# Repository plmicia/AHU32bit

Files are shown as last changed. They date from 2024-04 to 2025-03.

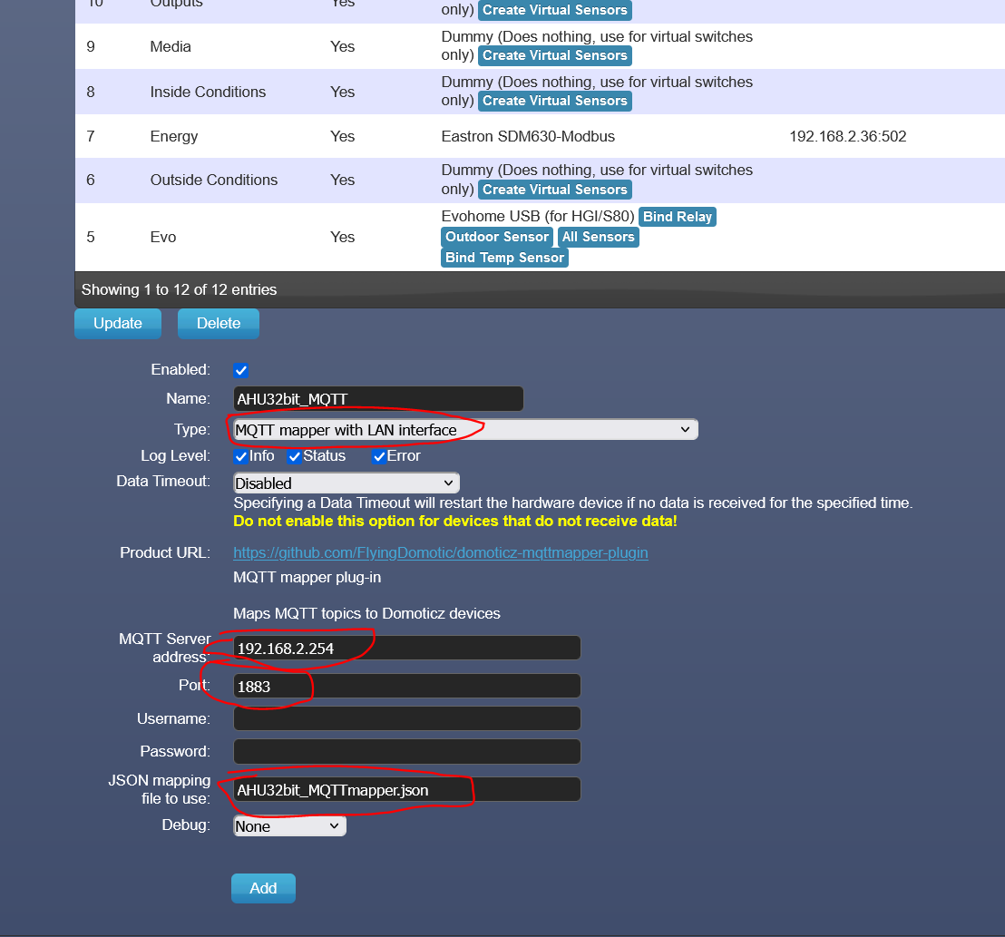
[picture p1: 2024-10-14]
Firmware v3.0.6beta/MQTT Domoticz/konfiguracja Domoticz - devices.PNG

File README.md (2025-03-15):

# AHU32bit 

Heat Pump Controller

Jak połączyć AHU do sieci lokalnej?
https://youtu.be/T4DrFWYFrpU?si=GrnXhtAI3-qEB1rJ

Jak zaktualizować firmware?
https://youtu.be/g_uAfUcfIxk?si=aBbPRCSxZJbn4i6s

**v1.0.0:**
 
Wersja wyjściowa

**v1.1.1:**

Dodanie menu "Wyświetlacz LCD" w którym można:
- ustawić wartość podświetlenia
- ustawić wygaszenie podświetlenia po czasie
- ustawić wartość podświetlenia po wygaszeniu
- zał./wył. wyświetlanie częstotliwości pracy sprężarki na ekranie głównym
  
Dodanie możliwości zablokowania klawiatury poprzez przytrzymanie (~1s) dwóch środkowych przycisków.

Dodanie dłuższego (~1s) przytrzymania przycisku ON/OFF (ochrona przed przypadkowym naciśnięciem).

Możliwość kalibracji czułości przycisków z poziomu konsoli AHU32bit.

Poprawka drobnych błędów:
- likwidacja, występującego czasami, stałego pisku przy wyłączaniu alarmu
- zapis wartości nastawionej temperatury do pamięci przy zaniku zasilania

**v1.1.2:**

- poprawka błędów

**v1.2.3:**

Dodanie menu "Pompa obiegowa" w którym można:
- Ustawić postcyrkulację (opóźnienie wyłączenia pompy obiegowej)
- Wysterować stałą mocą pompę wyposażoną w wejście PWM
- Ustawić parametry wyjścia PWM (częstotliwość PWM)
W menu "Defrost" dodano możliwość ograniczenia czasu wymuszonego defrstu oraz dodano opóźnienie wyłączenia przekaźnika sygnalizującego defrost.

W menu "Zabezpieczenia" można wybrać, kiedy zabezpieczenie od przepływu ma być aktywne: "Zawsze", "Tylko gdy defrost" lub "Nigdy".

Dodano menu "Olejowanie" w którym można ustawić interwał olejowania, częstotliwośc (moc) sprężarki w czasie olejowania oraz czas trwania olejowania. Moża też wymusić olejowanie w celach diagnostycznych.

Dodano menu "Odzysk czynnika".

Poprawiono babole:
- wysterowanie przekaźnika pompy obiegowej
- zapisywanie do pamięci energii pobranej

**v1.3.4:**
- wprowadzono możliwość załącznia CO w zależności od t. zew. (w menu "Ustawienia CO")
- wprowadzono możliwość załączenia pompy obiegowej na zawsze, gdy sterownik jest załączony (w menu "Pompa obiegowa")
- poprawiono identyfikację agregatu 7kW 
- poprawiono wyświetlanie wartości EEV-A i EEV-B dla 7kW
- wprowadzono redukcję obrotów wentylatora przy wyższych temperaturach zewnętrznych dla agregatu 7kW

Poprawka błędów:
- ograniczono zakres nastaw maks. częstotliwość "łagodnego defrostu" od 56Hz do 85Hz
- sporadycznie występujące samoczynne, chwilowe startowanie agregatu, gdy T_cond > 20*C (dot. nowszych jednostek Gree i C&H >2022)
- wyeliminowanie problemów z wyłączaniem agregatu przed osiągnięciem temp zadanej (dot. nowszych jednostek Gree i C&H >2022)
- wyeliminowanie błędu uniemożliwiającego wymuszenie defrostu, gdy T_cond < (T_zew - 6)
- wyeliminowanie błędu uniemożliwiającego fabryczne wywołanie defrostu

**v2.0.0:**
- dodano nagłówki, ułatwiające poruszanie się po menu
- zmiana kroku nieczułości regulatorów CO i CWU z 0.5C na 0.1C
- uruchomiono funkcję ciepłomierza (konieczny czujnik przepływu!)
- rozdzielenie liczników energii: osobno dla CO i osobno dla CWU
- uruchomiono liczniki COP (konieczny czujnik przepływu i licznik energii!)
- dodano możliwość sterowania pompy obiegowej PWM w trybie stałej delty (menu: "Pompa obiegowa" -> "Tryb pracy PWM" -> "Stała delta")
- dodano stronę parametrów "Pompa obiegowa", gdzie można podejrzeć aktualny stan załączenia pompy obiegowej, wartości PWM i deltę.
- dodano możliwość wywołania olejowania co 3h
- zmieniono krok zadawania stałej mocy pracy pompy obiegowej PWM (było co 10%, jest co 1%)
- poprawiono działania klawiszy + i -, dodając funkcję przytrzymania z autoinkrementacją. Po naszemu: przytrzymać dłużej przycisk, aby wartość sama się zwiększała lub zmniejszała
- dodano menu "Liczniki", w którym można wyzerować wartość licznika energii, ilość defrostów, czas pracy sprężarki i ilość załączeń
- wprowadzono dynamic clamping we wszystkich regulatorach PI (znacznie poprawia dynamikę sterowania)

Poprawka błędów:
- wyeliminowanie błędu załączenia CWU wraz z blokadą załączenia CO od T_zew + dodanie ikonki sygnalizującej wyłączenia od temperatury zewnętrznej.
- próba wyeliminowania błędu uniemożliwiającego wymuszenie defrostu (dot. nowszych jednostek Gree i C&H >2022)

Uwaga!!! Aby liczniki energii działały prawidłowo, od teraz po każdej aktualizacji trzeba w pełni zrestartować system (zdjąć zasilanie z płytki bazowej na min. 20 sek.)

**v2.0.1:**

Poprawka błędów:
- aktywacja regulatora CWU

**v2.0.2:**

Poprawka błędów:
- Zapis wartości liczników do pamięci, zaraz po wyzerowaniu w menu. Poprzenio, po zrestowaniu sterownika wartości wracały do wartości sprzed zerowania.
 
**v3.0.5:**
Video poradnik do aktualizacji: https://youtube.com/playlist?list=PL7Yoy5k4_2IOb-d7yyhNmrepyGyvrlC-8&si=gwIATBIfl5vukARS

Płytka wyświetlacza LCD:
- W menu "Ustawienia CO" dodano funkcję "Mniejsze taktowanie". Poprawia ona fabryczną procedurę zadawania częstotliwości sprężarki. Taktowanie jest jeszcze mniejsze, kosztem delikatnego przeregulowania w stanach dynamicznych. Załączenie funkcji pomaga wyeliminować wyłączenia sprężarki przy przełączaniu z CWU na CO oraz po "olejowaniu".
- Wprowadzono funkcję wyłączenia pompy obiegowej, gdy sterownik jest wyłączony od temperatury zewnętrznej (gdy ikonka "słoneczka" na ekranie głównym jest aktywna). Poprawnie ustawiona funkcja pozwala na poprawę COP całego układu, szczególnie w okresach przejściowych. 
- W menu "Liczniki" dodano możliwość wyboru pracy ciepłomierza: "Zawsze" lub "Gdy praca sprężarki". 
- "Moc oddana" o wartości z zakresu od -100W do 100W jest wyświetlana jako "0W" (zero watt) i nie jest wykorzystywana do liczenia energii oddanej. 
- Uporządkowano menu "Defrost". 
- Proszę nie korzystać! TESTY: Dodano funkcję "Indywidualny defrost", gdzie można ustawić: interwał defrostów, zwłokę defrostu po osiągnięciu progu, próg rozpoczęcia defrostu, maksymalny czas defrostu, próg zakończenia defrostu. Funkcja ogranicza lub eliminuje całkowicie występowanie tzw. suchych lub technicznych defrostów. 
- Dodano możliwość wprowadzenia offsetow w czujnikach temperatury w menu "Ust. czujników".
- Dodano identyfikację jednostki GWH09 (3,5kW).
- Wersję oprogramowania można sprawdzić w menu "Inne".
- Tymczasowo wyłączona zostaje funkcja "łagodny defrost". Funkcja wymaga poprawek.
  
Poprawki błędów:
- Strona "Energia": Gdy brak licznika energii pobranej w systemie, to "Moc pobrana" wyświetlana jest jako "0W", a nie "/W".
- Poprawiono błąd, uniemożliwiający start jednostki gdy temperatura parownika (T_cond)<(-9*C).
- Poprawiono drobne błędy w poruszaniu się po menu.

Konsola:
- Dodano obsługę MQTT
- UWAGA! Wyłączono obsługę Telnet.
- Dodano aplikację webową (AHU32bit Console) umożliwiającą podgląd parametrów online oraz podstawowe sterowanie w sieci lokalnej.
- Wprowadzono możliwość ustawienia stałego IP. 

Znane niedociągnięcia w konsoli:
- jeśli AHU nie połączy się z routerem w ciągu około 1 min, np. po utracie zasilania w domu, to konieczne będzie kliknięcie przycisku "zresetuj komunikację" w konsoli

Po aktualizacji należy zresetować system (płytkę LCD i płytkę bazową).

MQTT dla Home Assistant wspaniale opisał @Łukasz Wojtas.

**v3.0.6:**

Płytka wyświetlacza LCD:
- Poprawione wyświetlanie "PWM in" w konsoli i MQTT. Poprzednio wartość była odświeżana tylko gdy na LCD była wyświetlona strona "Pompa obiegowa". 
- Poprawiono zapisywanie wartości parametru "Licz ciepło i moc" z menu "liczniki" do pamięci nieulotnej.
- Wprowadzono możliwość podania wartości przełączenia biegów wentylatora JZ przy pracy CO. Progi dotyczą temperatury parownika i obowiązuje stała histereza 1C.
- Organiczno zakres nastaw czujnika przepływu do 1...1000imp/l
- Do menu "Ustawienia CO" wprowadzono możliwość ustawienie progów zmiany obrotów wentylator jednostki zewnętrznej: "Próg 390/450(490)rpm" oraz "Próg 490/690(790)rpm". Histereza jest stała i wynosi 1C.

Konsola:
- Zmieniono nazwę klienta Mqtt z esp8266client-xxxx na AHU32bit_Client_xxxx
- Poprawiono literówka w słowie "Sprężarka" w zakładce "temperatury".
- Poprawiono wskaźnik temperatury "Falownik" dla jednostki 5kW.
- Wersja konsoli jest wyświetlana w zakładce "Inne"

**v3.0.11:**

UWAGA! Podczas aktualizacji bardzo ważna jest kolejność wgrywania plików!
Video pordanik: https://youtu.be/dtAwadvea6k?si=yNV6m9RhdPWOf3Bx

Płytka wyświetlacza LCD:
- Dodano obsługę GWH12
- Dodano obsługę CH-S24FTXAL-WP
- Dodano zapis parametrów do pamięci przed aktualizacją 
- Zmieniono nazwy temperatur w zakładce 'temperatury' na polskie
- Dodano zabezpieczenie od zamarznięcia parownika. Jeśli różnica temperatury między parownikiem a zewnętrzną przekracza próg z menu ORAZ utrzymuje się przez czas ustawiony w menu, to agregat się wyłączy. Dostępne nastawy w menu "Zabezpieczenia": 
"Min. delta par.-zew.:" oraz "Min. czas błędu par.:"
Alarm sygnalizowany jest na ekranie: Err!(T*)
- Zmieniono dostępne nastawy dla pracy pompy obiegowej: 
"Zawsze gdy ON"
"Gdy praca sprężarki"
"Gdy żądanie CO/CWU"
- Dodano włączenie pompy obiegowej zawsze przy olejowaniu
- Gdy defrost aktywny, to zawór 3D (przekaźnik AUX) zostaje wyłączony. W ten sposób defrost zawsze robiony jest na zład CO.
- Poprawka wysterowania pompy PWM po błędzie zaniku przepływu. 
BYŁO: wartość wynikająca z regulatora delty lub aktualnie ustawiona stała moc.
JEST: 100% mocy
- Zmieniono komendę włączającą najwyższe obroty wentylatora. Lepsza praca przy wyższych mocach i niższych temperaturach.
- Dodano funkcję zapisującą przed aktualizacją aktualne wartości liczników do pamięci.

Konsola:
- W zakładce "Sprężarka" dodano do zegara wyświetlanie częstotliwości zadawanej przez AHU.
- W zakładce "Inne" wyświetlana jest wersja software dla LCD oraz Konsoli.

Po aktualizacji należy zresetować system (płytkę LCD i płytkę bazową).

**v3.1.2:**

Płytka wyświetlacza LCD:
- Uruchomiono funkcję "Indywidualny defrost" w której można indywidualnie sprofilować przegieg defrostu (łagodnie/agresywnie, itp.).

Aby aktywować w pełni "Indywidualny defrost" należy: 
1. Włączyć w menu "Defrost" - > "Indywidualny defrost" -> "Aktywny" na TAK
oraz
2. Włączyć w menu "Defrost" - > "Własny profil" -> "Aktywny" na TAK

Indywidualny defrost jest dwufazowy:
a) faza pierwsza ok. 45Hz, około 3 min,
b) faza II: 65Hz, około 3 min lub szybciej, jeżeli temperatura parownika >20C (lub inna nastawiona).

Dostępne parametry w menu "Indywidualny defrost":
- "Interwał:" czas po którym AHU zacznie sprawdzać temperaturowy próg wyzwolenia defrostu (parametr: "Start defrsotu:"). Wartość domyślna: 90 min. (1,5h).
- "Start defrsotu:" próg temperaturowy wyzwolenia defrostu. Wartość domyślna: -4C. UWAGA! Nie jest to żadna wartość bezwzględna. Jest to różnica temperatur między temperaturą parownika, a temperaturą zewnętrzną!!!
- "Maks. czas defrostu:" czas po którym defrost zostanie ukończony, bez względu na uzyskaną temperaturę parownika. Wartość domyślna: 10 min. Wartość powinna być większa niż suma: 3min + "Faza I (sek.):" + "Faza II (sek.):"
- "Koniec defrostu:" osiągnięcie tej temperatury na parowniku zakończy defrost. Wartość domyślna: 20C
- "Faza I (Hz):" częstotliwość sprężarki podczas fazy I defrostu. Wartość domyślna: 45Hz.
- "Faza I (sek.):" czas trwania fazy I defrostu. Wartość domyślna: 180sek. (3 min)
- "Faza II (Hz):" częstotliwość sprężarki podczas fazy II defrostu. Wartość domyślna: 65Hz.
- "Faza II (sek.):" czas trwania fazy II defrostu. Wartość domyślna: 180sek. (3 min)

Wartości domyślne, są zbliżone do fabrycznych. 

Jeśli defrosty mają być wykonywane częściej, należy zmniejszyć wartość "Interwał" np. z 90 min do 75 min lub zmienić wartość "Start defrostu" (np. zamiast wartości -4C ustawić -3C).
Jeśli defrosty mają być wykonywane rzadziej, należy zwiększyć wartość "Interwał" np. z 90 min do 120 min lub zmienić wartość "Start defrostu" (np. zamiast wartości -4C ustawić -6C).
Jeśli defrost ma przebiegać łagodniej, to należy poeksperymentować z nastawami: "Faza I (Hz):" oraz "Faza II (Hz):". Proszę pamiętać, że zminiejszenie tej wartości może spowodować konieczność wydłużenia defrostu szeczególnie nastawy "Faza II (sek.):" oraz "Maks. czas defrostu:"

Dodatkowo warto zweryfikować nastawy zabezpieczeń w menu "Zabezpieczenia":
- "Minimalna tempeartura rury cieczowej:" próg zadziałania zabezpieczenia od za niskiej temperatury na rurze cieczowej. Wartość należy dobrać do swojej instalacji eksperymentalnie. Wartość domyślna: -5C.
- "Minimalny przepływ:" próg zadziałania zabezpieczenia od za niskiego przepływu. Wartość należy dobrać do swojej instalacji eksperymentalnie. Wartość domyślna: 500l/h.
- "Minimlany czas błędu:" po tym czasie od przekroczenia progu błędu, zostanie zasygnalizowany błąd. Wartość domyślna: 2s. Wartość zalecana: 1-5s.
- "Minimalna delta parownik-zewnętrzna:" próg temperaturowy wyzwolenia zabezpieczenia od zamarznięcia parownika. Wartość domyślna: -10C. UWAGA! Nie jest to żadna wartość bezwzględna. Jest to różnica temperatur między temperaturą parownika, a temperaturą zewnętrzną!!!
- "Minimalny czas błędu parownik-zewnętrzna" po tym czasie od przekroczenia progu błędu "Minimalna delta parownik-zewnętrzna:", zostanie zasygnalizowany błąd. Wartość domyślna: 90 min (1,5h). Wartość zalecana: dłuższa lub równa "Interwał:" w menu "Indywidualny defrost".

Zaleca się ustawić "Postcyrkulację" na minimum 5 min. w menu "Pompa obiegowa".

Defrost indywidualny jest sygnalizowany na ekranie głównym napisem 'CUSTOM' pod ikoną śnieżynką, w momencie jego trwania. 
Odliczany minimalny czas do kolejnego defrostu, widoczny jest w zakładce "Defrost".
Odliczany maksymalny czas do zakończenia trwającego defrostu, widoczny jest w zakładce "Defrost".
Praca sprężarki podczas defrostu indywidualnego rozpoczyna się po około 3 min, od ukazania się ikonki sygnalizującej defrost ("śnieżynka").
Przełączenie na grzania po zakończeniu defrostu trwa około 3 min.

Aby próbnie wywołać defrost indywidualny, należy wybrać "Wymuś indywidualny defrost". Na rozpoczęcie fazy I defrostu trzeba poczekać około 3min.

"Defrost indywidualny" nie powoduje blokowania defrostu fabrycznego. Jeśli agregat uzna, że musi wykonać "suchy" lub "techniczny" defrost to go wykona.

Warunki rozpoczęcia odliczania w dół do "Indywidualnego defrostu": praca sprężarki ORAZ temperatura parownika <0C. Jeśli w czasie odliczania temperatura parownika będzie >=0C, to czas do defrostu zacznie się liczyć do góry (zwiększać się). Może się tak stać np. nad ranem, gdy temperatura zewnętzna urośnie.

Waruknki rozpoczęcia "Indywidualnego defrostu": odliczony  czas (nastawa "Interwał") ORAZ spełniony warunek temperaturowy (nastawa "Start defrostu").

Warunki zakończenia "Indywidualnego defrostu": osiągnięcie zadanej temperatury na parowniku (nastawa "Koniec defrostu:") LUB minięcie nastawy czasu "Faza I (sek.):" + "Faza II (sek.):" LUB minięcie nastawy czasu "Maks. czas defrostu:".

- Menu "Defrost": usunięto funkcję "Łagodny defrost" w starym wydaniu. Zastąpiono ją nową funkcją "Własny profil".

**v3.1.3:**

Aktualizacja od wersji 1.x.x lub 2.x.x :https://www.youtube.com/watch?v=skZjCgosQtY&list=PL7Yoy5k4_2IOb-d7yyhNmrepyGyvrlC-8&index=1&t=78s
Aktualizacja od wersji: 3.x.x: https://youtu.be/dtAwadvea6k?si=yNV6m9RhdPWOf3Bx

UWAGA! Podczas aktualizacji bardzo ważna jest kolejność wgrywania plików!

Płytka wyświetlacza LCD:
- Zmodyfikowano sposób wyświetlania wartości czasu do kolejengo defrostu w zakładce "Defrost". 
BYŁO: wartość w sekundach
JEST: wartość w formacie HH:MM:SS

- Zmodyfikowano sposób wyświetlania wartości czasu do zakończenia defrostu w zakładce "Defrost". 
BYŁO: wartość w sekundach
JEST: wartość w formacie MM:SS

- Dodano możliwość wyboru sposobu raportowania T gaz do JZ w menu "Ust. czujników"->"Pomiar T gaz"->"Sposób pomiaru":
  
a) "Tylko T gaz" - AHU raportuje do JZ T gaz jako rzeczywistą pomierzoną wartość, bezpośrednio z czujnika

b) "Średnia T gaz i T ciecz" - AHU raportuje do JZ i wyświetla T gaz, jako średnią ważoną pomiaru T gaz oraz T ciecz. Wagi również można ustawić w menu 

- Odliczanie do kolejnego defrostu:
BYŁO: resetowanie po wystąpieniu błędu (odliczanie od początku)
JEST: pozostaje poprzednia wartość

- Wzmocniono filtrowanie progów błędu od za niskiej temperatury, przepływu i delty zew.-parownik.

Konsola:

- poprawiono layout zakładki "Inne" na urządzeniach mobilnych (wyświetlanie kafelka z wersją oprogramowania)
- zmieniono zakres wskaźników dla temperatur ujemnych, BYŁO: 0C - 100C, JEST -40C - 100C

**v3.2.6:**

Płytka wyświetlacza LCD:

- Zwiększono czytelność wprowadzania nastaw zadanej temperatury po naciśnięciu klawiszy plus i minus (wyświetlanie dodatkowego okna pop-up).
- Zamieniono przycisk "minus" z "plus" i vice versa, aby był spójny z układem przycisków w konsoli. 
- Zamieniono przycisk "up" z "down" i vice versa.
- Zmieniono miejsce wyświetlania częstotliwości, tak aby była widoczna podczas przeglądania zakładek oraz menu (prawy górny róg). 
- Dodano możliwość wyświetlenia dwóch dodatkowych parametrów na ekranie głównym. Wyboru parametrów w można dokonać w menu "Wyświetlacz LCD" ->"Pokaż na stronie głównej [pole I]" oraz "Pokaż na stronie głównej [pole II]". 
- Poprawiono raportowanie "PWM out" podczas trwania defrostu, itp.
- Poprawiono raportowanie częstotliwości zadanej podczas trwania defrostu oraz olejowania.
- Dodano wyświetlanie przepływu w zakładce "Pompa obiegowa".
- W menu "Inne" można włączyć/wyłączyć "Dźwięk alarmów" (pikanie).
- Wydłużono czas stanu "Aktualnie pod indywidualnym defrostem" o 3 min od momentu wyłączenia sprężarki.
- Dodano możliwość ustawienia obrotów wentylatora JZ podczas olejowania (w mneu "Olejowanie")
- Dodano możliwość ustawienia progu załączenia maksymalnej (810rpm) wartości obrotów wentylatora JZ (w menu "Ustawienia CO"->"Wentylator JZ")
- Korekta wyświetlanych wartość w zakładce "Energia", szczególnie po wyzerowaniu liczników.

Konsola:

- Gdy "Indywidualny defrost" włączony, dodano kafelek odliczający czasy do kolejnego defrostu i do zakończenia defrostu.
- Poprawiono wyświetlanie flagi "Aktualnie pod defrostem" podczas trwania defrostu indywidualnego.
- Poprawiono wysyłanie do konsoli i MQTT flagi "Aktualnie pod indywidualnym defrostem".
- Dodano wyświetlanie drugiej temperatury parownika (przydatne przy diagnostyce gazowej).
- Dodano do protokołu MQTT wysyłanie wersji firmware LCD.

**v3.2.8:**

Płytka wyświetlacza LCD:

- W menu "Defrost"->"Fabryczne defrosty" dodano możliwość pomijania fabrycznych defrostów (w tym suchych/technicznych).

Możliwe nastawy:

"Wykonuj" - nastawa standardowa. Gdy agregt zadecyduje o defroście (nawet suchym/technicznym) to AHU nie zablokuje jego wykonania.

"Pomijaj" - gdy AHU otrzyma z agregartu sygnał o rozpoczęciu fabrycznego defrostu, to wyłącza agregat i załącza grzanie ponownie. 

UWAGA! Efekt uboczny: przerwa ok. 3 min w pracy agregartu! 
Nastawa "Pomijaj", będzie aktywna tylko gdy "Indywidialny defrost" ustawiony na "TAK" ORAZ "Własny profil" ustawiony na "TAK".  

**v4.0.9:**

UWAGA! UWAGA! UWAGA!
Kolejność wgrywania plików inna niż zwykle:
1. AHU32bit_Console_Firmware.bin
2. AHU32bit_LCD_Firmware.bin
3. AHU32bit_Console_FileSystem.bin
   
Wideo poradnik: https://www.youtube.com/watch?v=JyJtdb9cDpk

Płytka wyświetlacza LCD:

- Dodano dwupunktową linearyzację czujnika przepływu YF-B10. Poprawia dokładność liczenia mocy i energii oddanej dla małych przepływów. Szczególnie ważne dla pomp obiegowych PWM!
Funkcję można włączyć w 'Menu'->'Ust. czujników'->'Czujnik przepływu'->'Linearyzacja'->'Dwupunktowa'.
Wartości domyślne obowiązują dla czujnika YF-B10.
Własne wartości można podać w parametrach, gdy parametr "Linearyzacja" jest ustawiony na "Jednopunktowa":
"Przepływ-odczyt min.:" wartość przepływu odczytana przez AHU @ 10% PWM
"Przepływ-znany min.:" wartość przepływu odczytana z fabrycznego ciepłomierza/miernika przepływu @ 10% PWM
"Przepływ-odczyt max.:" wartość przepływu odczytana przez AHU @ 100% PWM
"Przepływ-znany max.:" wartość przepływu odczytana z fabrycznego ciepłomierza/miernika przepływu @ 100% PWM
Po podaniu własnych wartości należy przestawić parametr "Linearyzacja" na "Dwupunktowa"
Wartości PWM dla pompy obiegowej, można zadać w trybie pracy pompy obiegowej "Stała moc" w menu "Pompa obiegowa".
- W menu „Ustawienia CO” dodano funkcję "Łagodny rozruch CO" przybliżającą profil rozruchu do fabrycznego sterowania. Uwaga! Funkcja jest domyślnie AKTYWNA. Dezaktywacji można dokonać w menu.
Aktywność funkcji jest sygnalizowana na wyświetlaczu za pomocą ikonki z napisem "Soft".
- Dodano zakładkę "Alarmy", gdzie można podejrzeć aktualne błędy AHU oraz jednostki zew. Błędy AHU32bit są opisane wraz z podpowiedzią gdzie szukać rozwiązania. Błędy agregatu opisane są zgodnie z fabrycznym opisem z dokumentacji serwisowej (po angielsku, wg. oryginalnej pisowni).
Uwaga! Pojawienie się błędu agregatu (jednostki zewnętrznej) nie powoduje zatrzymania AHU32bit. W przypadku ustania błędu, jednostka zewnętrzna powinna powrócić do pracy.
- Dodano zegar RTC wyświetlany na pasku górnym. Zegar można nastawić w menu "Wyświetlacz LCD"->"Zegar RTC". Zegar można też ukryć zmieniając nastawę parametru "Pokaż zegar na pasku" w tym samym menu. Aby zegar chodził po utracie zasilania, do panelu LCD należy włożyć litową bateryjkę pastylkową 3V typu CR1220. 
- Sygnalizacja trybu "Emulacji jednostki wewnętrznej" ikonką na ekranie głównym "EMU"
- Delikatna zmiana w regulatorze stałej delty pompy obiegowej - poprawa dynamiki. 
- W trybie "Emulacji fabrycznej jednostki wewnętrznej" ignorowane jest "Olejowanie" oraz "Indywidualny defrost". Nastawa "Pomijaj fabryczne defrosty" również jest ignorowana.
- Po załączeniu funkcji odzysku czynnika, pompa obiegowa jest załączana na maks. moc.
- Poprawiono literówki w menu (np. "ź" zamiast "z" w "Dźwięk alarmów", itp.)
- Zmodyfikowano protokół komunikacyjny między LCD a modułem komunikacyjnym ESP

Konsola:

- Dodano możliwość pełnego zdalnego sterowania LCD z poziomu konsoli. Z uwagi na ograniczenia sprzętowe pasma transmisyjnego widok ekranu LCD jest odświeżany około raz na sekundę. Należy mieć na uwadze delikatne opóźnienia przeglądając menu zdalnie. Wskazana cierpliwość przy modyfikowaniu nastaw. Funkcja z założenia do wykorzystania sporadycznego ;-). 
- Zmodyfikowano obszar nastawiania temperatury zadanej. Dodano wskaźnik graficzny aktualnego przesunięcia równoległego gdy krzywa grzewcza/pogodowa jest aktywna oraz wskaźnik graficzny zadanej temperatury gdy krzywa grzewcza/pogodowa nie jest aktywna. 
- Dodano zakładkę "Alarmy", gdzie można podejrzeć aktualne błędy AHU oraz jednostki zew. Błędy AHU32bit są opisane wraz z podpowiedzią gdzie szukać rozwiązania. Błędy agregatu opisane są zgodnie z fabrycznym opisem z dokumentacji serwisowej (po angielsku, wg. oryginalnej pisowni).
- Dodano możliwość załączenia i wyłączenia ahu oraz modyfikacji temperatury zadanej z poziomu MQTT. UWAGA! KAŻDA ZMIANA POWODUJE ZAPIS PARAMETRÓW DO PAMIĘCI NIEULOTNEJ WYŚWIETLACZA LCD! NIE JEST ZALECANA MODYFIKACJA PARAMETRÓW W SPOSÓB CIĄGŁY (NP. REALIZACJA KRZYWEJ POGODOWEJ) Z UWAGI NA OGRANICZONĄ ILOŚĆ CYKLI ZAPISÓW DO PAMIĘCI. 
- Zmodyfikowano protokół komunikacyjny między LCD a modułem komunikacyjnym ESP
- Dodano do transmisji MQTT topic: "AHU32bit/realtime/LCD_firmware", gdzie raportowana jest wersja firmware LCD w postaci stringa X.X.X.
- Zmiana biblioteki MQTT na asynchroniczną.

Poprawki konsoli:
- informacje na temat indywidualnego defrostu w zakładce "defrost" (np. odliczanie czasu, itp.) są ukrywane w trybie "Emulacji jednostki wew."

Uwaga! Z uwagi na zwiększone obciążenie transmisji danych, sporadycznie (szczególnie w czasie zdalnego przeglądania menu LCD) może pojawić się glitch (zakłócenie) w transmisji. Objawia się on w postaci szpilki na wykresach z rejestracji pracy sterownika.

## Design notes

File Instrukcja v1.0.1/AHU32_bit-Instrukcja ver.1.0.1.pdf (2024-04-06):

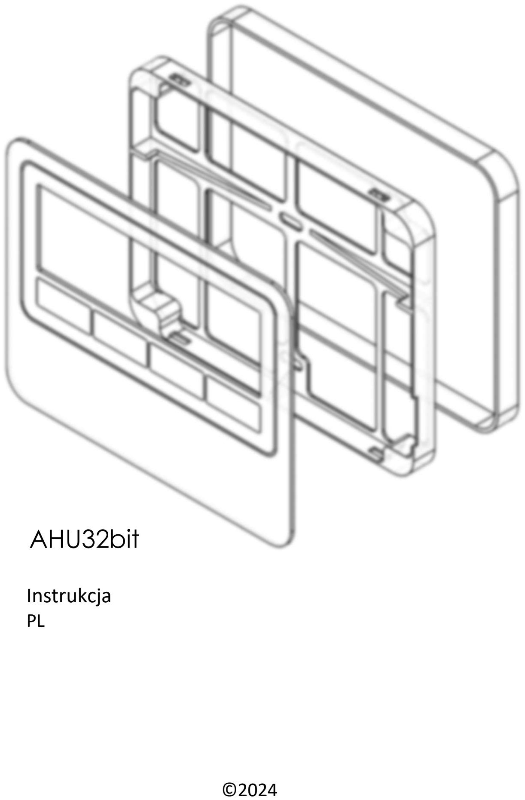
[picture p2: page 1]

©2024

## AHU32bit

### Instrukcja

PL

FabLabPro
ver. 1.0.1.

©2024
v1.0.0.
FabLabPro | 2 / 2 0

## Spis treści:

ver. 1.0.1.

©2024
v1.0.0.
FabLabPro | 3 / 2 0

### 1. Wstęp

Dziękujemy za zakup sterownika AHU32bit. Niniejsza instrukcja pokaże jak zamontować i uruchomić sterownik w poprawny i bezpieczny sposób. Dopełniliśmy wszelkich starań, aby jego instalacja sprawiła wiele przyjemności, a efekt cieszył oko przez długi czas. W razie jakichkolwiek pytań, czy uwag prosimy się zgłaszać pod adres e-mail: ciackamichal@gmail.com. Chcąc być na bieżąco z
aktualizacjami | oraz | wiadomościami | subskrybuj | media
społecznościowe projektu:
| AHU32bit
| AHU32bit
| #AHU32bit
Pompa ciepła - OPEN SOURCE Projekt sterowania i monitoringu w jednym
POMPA CIEPŁA - ࡀ࠿ JAK ZROBIĆ ࡀ࠿ -
| FORUM

### 2. Zawartość zestawu

W jego skład wchodzą:
- Zmontowana płytka drukowana LCD (1 szt.)
- Zmontowana płytka drukowana Bazowa (1 szt.) z wtyczkami
- Kołki montażowe do płytki BAZA (4 szt.)
- Ramka montażowa do płytki LCD (1 szt.) - GRATIS
- Czujniki temperatury typu NTC 10k B3950 (4 szt.)
- Izolacja termokurczliwa z oznaczeniami czujników (8 szt.)
- Kabel 1m typu Ethernet RJ45 (1 szt.)

ver. 1.0.1.

©2024
v1.0.0.
FabLabPro | 4 / 2 0

### 3. Podstawowe cechy

Ważne!
Sterownik jest przeznaczony do wbudowania w istniejący system grzewczy z pompa ciepła. Sterownik nie jest przeznaczony do pracy poza systemem grzewczym!
Sterownik AHU32bit to urządzenie umożliwiające sterownie prestiżowymi agregatami powietrznymi. AHU32bit zastępuje jednostkę wewnętrzną. Podstawowym zadaniem AHU32bit jest stabilizacja temperatury zasilania systemu grzewczego na zadanym poziomie. Możliwy jest wybór temperatury grzania za pomocą wejść bezpotencjałowych, osobno dla CO i CWU.
Uwaga! Do pełnej pracy w trybie CWU niezbędny jest sterownik (termostat) załączający zawór 3D oraz ewentualni dodatkową pompę.
Stabilizacja jest w pełni proporcjonalna i w zakresie modulacji instalacji.
Zadana wartość temperatury może pochodzić z krzywej grzewczej lub mieć stałą wartość.
Właściwości:
- Duży, czytelny wyświetlacz graficzny (4.5”).
- Przyciski dotykowe.
- Tryb Lato/zima.
- Krzywa pogodowa.
- Podgląd wszystkich parametrów dostępnych w systemie:
- Temperatury: zasilania, powrotu, gazu, cieczy, zewnętrznej, parownika, sprężarki, falownika,
- Parametry pracy sprężarki: częstotliwość, moc elektryczna (konsumowana), energia elektryczna (konsumowana), prąd AC, napięcie DC.
- Wysterowanie EEV,

ver. 1.0.1.

©2024
v1.0.0.
FabLabPro | 5 / 2 0
- Obroty wentylatora jednostki zewnętrznej,
- Funkcje statystyczne:
- Ilość załączeń sprężarki,
- Ilość defrostów,
- Łączny czas pracy sprężarki
- Wyjścia przekaźnikowe:
- Sygnalizacja defrostu,
- Alarm,
- Pompa obiegowa,
- AUX (docelowo do sterownia biwalentnego).
- Zabezpieczenia:
- Zaniku przepływu,
- Spadku temperatury,
- Błędu czujnika.
- Sterowanie pogodowe

### 4. Niezbędne narzędzia i materiały do montażu

Zakładamy, że osoba montująca sterownik AHU32bit posiada zaawansowaną wiedzę i umiejętności w zakresie pomp ciepła oraz elektryki. Płytkę bazową sterownika należy zabudować w szczelnej szafie sterowniczej. Płytkę wyświetlacza LCD zamontować na zewnątrz szafy sterowniczej w dostępnym miejscu. Z elementami sterownika należy się obchodzić delikatnie.
Niezbędne narzędzia:
- Mały wkrętak płaski (max. 3mm)
- Przewód do przedłużenia czujników temperatury (doskonale nadaje się skrętka internetowa, ma akurat 4 skręcone pary przewodów). Długość przewodów należy dostosować do własnej instalacji.

ver. 1.0.1.

©2024
v1.0.0.
FabLabPro | 6 / 2 0
- Złączki lub lutownica i cyna do połączenia przewodów z czujnikami

Może się również przydać:

- Wiertarka
- Wiertła
- Praska do zaciskania tulejek na przewodach

### 5. Montaż mechaniczny

Płytkę bazową należy zamontować w szafce sterowniczej tak, aby zapewnić swobodny dostęp do złącz. W przypadku montażu na płycie montażowej, można do tego celu użyć kołków montażowych dostarczonych w zestawie.

UWAGA!!! W sterowniku, podczas pracy występuje napięcie niebezpieczne dla zdrowia i życia człowieka. Montaż oraz podłączenie należy przeprowadzić ze szczególną ostrożnością, przy wyłączonym napięciu!

ver. 1.0.1.

©2024
v1.0.0.

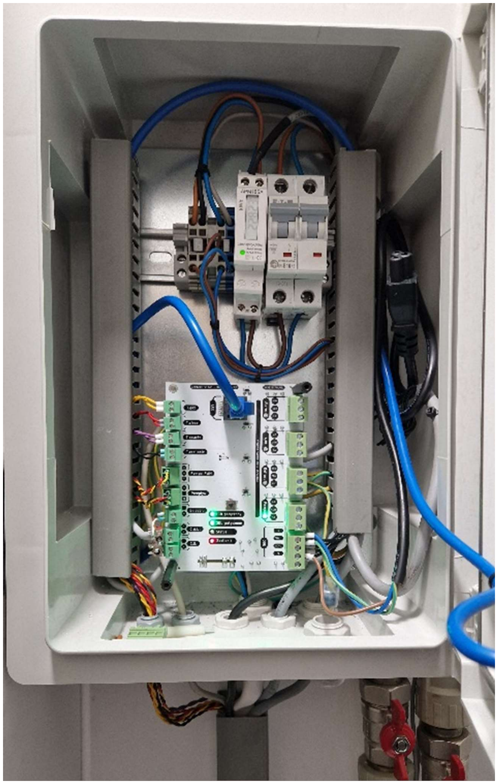
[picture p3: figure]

FabLabPro | 7 / 2 0

Płytkę LCD można zamontować na elewacji za pomocą dostarczonej w zestawie ramki montażowej. Ramka jest też przystosowana do montażu ze standardową puszką instalacyjną 60mm.

ver. 1.0.1.

©2024
v1.0.0.

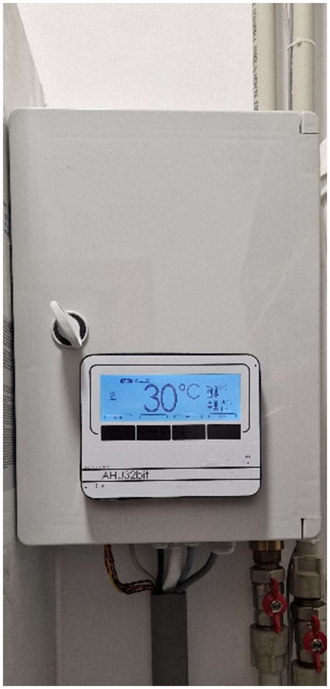
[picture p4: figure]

FabLabPro | 8 / 2 0

Po montażu można zdjąć folie ochronne na ekranie oraz ramce montażowej.

### 6. Podłączenie

### 6.1 Podłączenie sygnału żądania grzania CO i CWU

Aby sterownik rozpoczął pracę konieczne jest podanie sygnału zewnętrznego na bezpotencjałowe wejście żądania grzania CO lub CWU.

W klasycznej aplikacji na wejściu żądania CO należy wykonać zworę, a do wejścia żądania grzania CWU naley podłączyć termostat.

ver. 1.0.1.

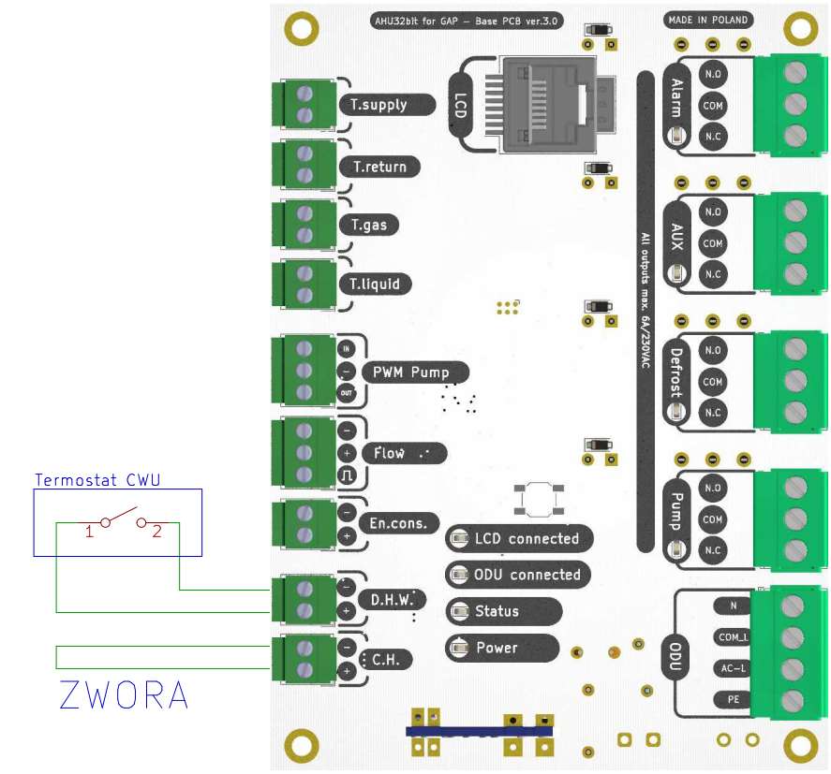
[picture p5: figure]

©2024
v1.0.0.
FabLabPro | 9 / 2 0

Termostat CWU należy podłączyć zgodnie z zaleceniami producenta. Należy pamiętać, że wejście żądania grzania CWU w AHU32bit jest bezpotencjałowe.

Uwaga! Pojawienie się potencjału na wejściu żądania grzania CO oraz CWU uszkodzi sterownik!

### 6.2 Podłączenie zasilania i komunikacji z agregatem

Podłączenie zasilania i komunikacji z agregatem dokonujemy identycznie jak dla fabrycznej jednostki wewnętrznej.

ver. 1.0.1.

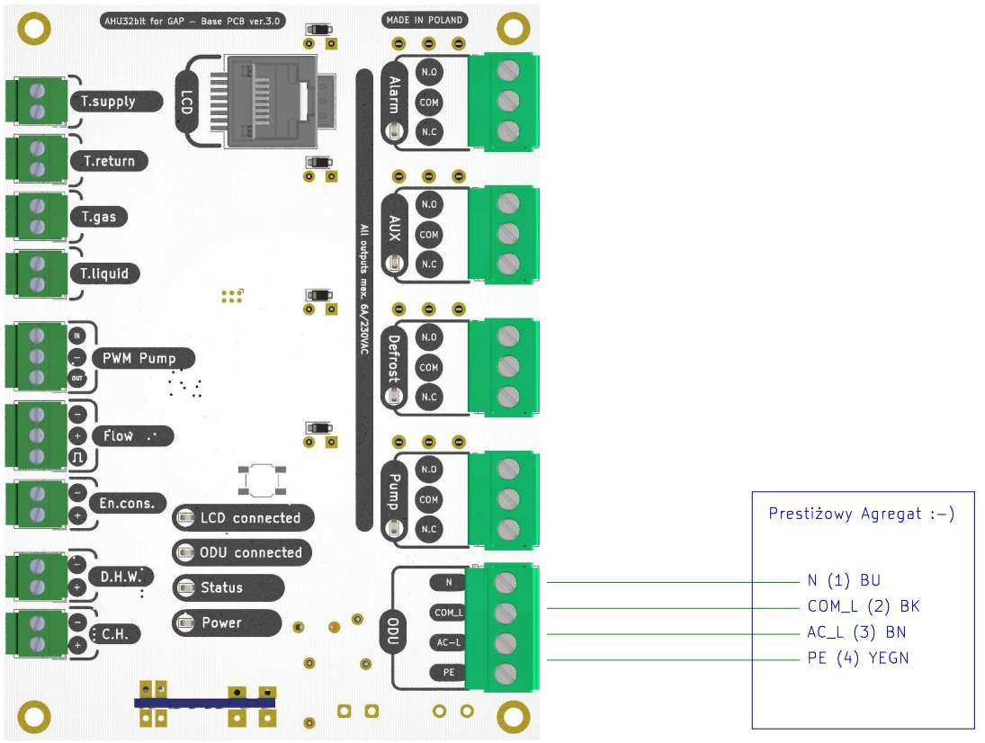
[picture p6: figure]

©2024
v1.0.0.
FabLabPro | 1 0 / 2 0

### 6.3 Podłączenie z wyświetlaczem LCD

Połączenie miedzy płytką Bazową, a płytką LCD należy dokonać za pomocą dołączonego do zestawu przewodu zgodnego ze standardem Ethernet (skrętka RJ45).

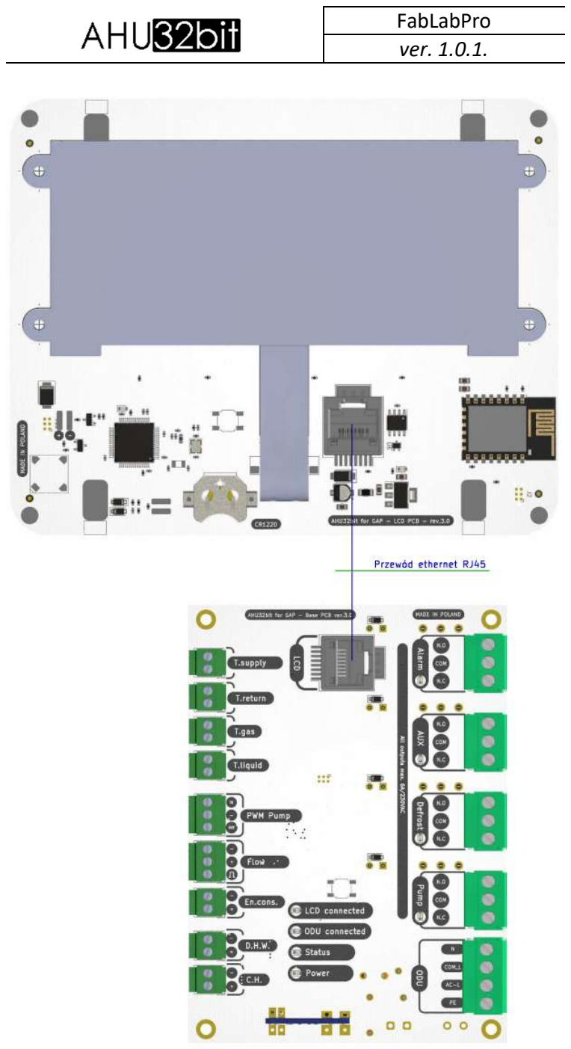
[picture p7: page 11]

ver. 1.0.1.

©2024
v1.0.0.
FabLabPro | 1 1 / 2 0

ver. 1.0.1.

©2024
v1.0.0.
FabLabPro | 1 2 / 2 0

W przypadku oddalenia płytki LCD od płytki Bazowej ponad 1m połączenie należy wykonać we własnym zakresie.
Uwaga! Płytka LCD jest zasilana tym przewodem! Należy stosować dobrej jakości skrętkę miedzianą, aby zniwelować spadki napięcia na przewodzie.

### 6.4 Podłączenie czujników temperatury

Ważne!
Prawidłowe zamontowanie czujnika na zasilaniu oraz czujnika na rurze gazowej jest kluczowe do prawidłowej pracy systemu!

AHU32bit współpracuje z termistorami typu NTC 10k B3950.
Tam gdzie jest to możliwe, zalecane jest montowanie czujników temperatury z użyciem kapilar. W przypadku niemożliwości zastosowania kapilar, należy czujnik solidnie zamontować do powierzchni mierzonego elementu za pomocą taśm izolacyjnych i opasek zaciskowych.

ver. 1.0.1.

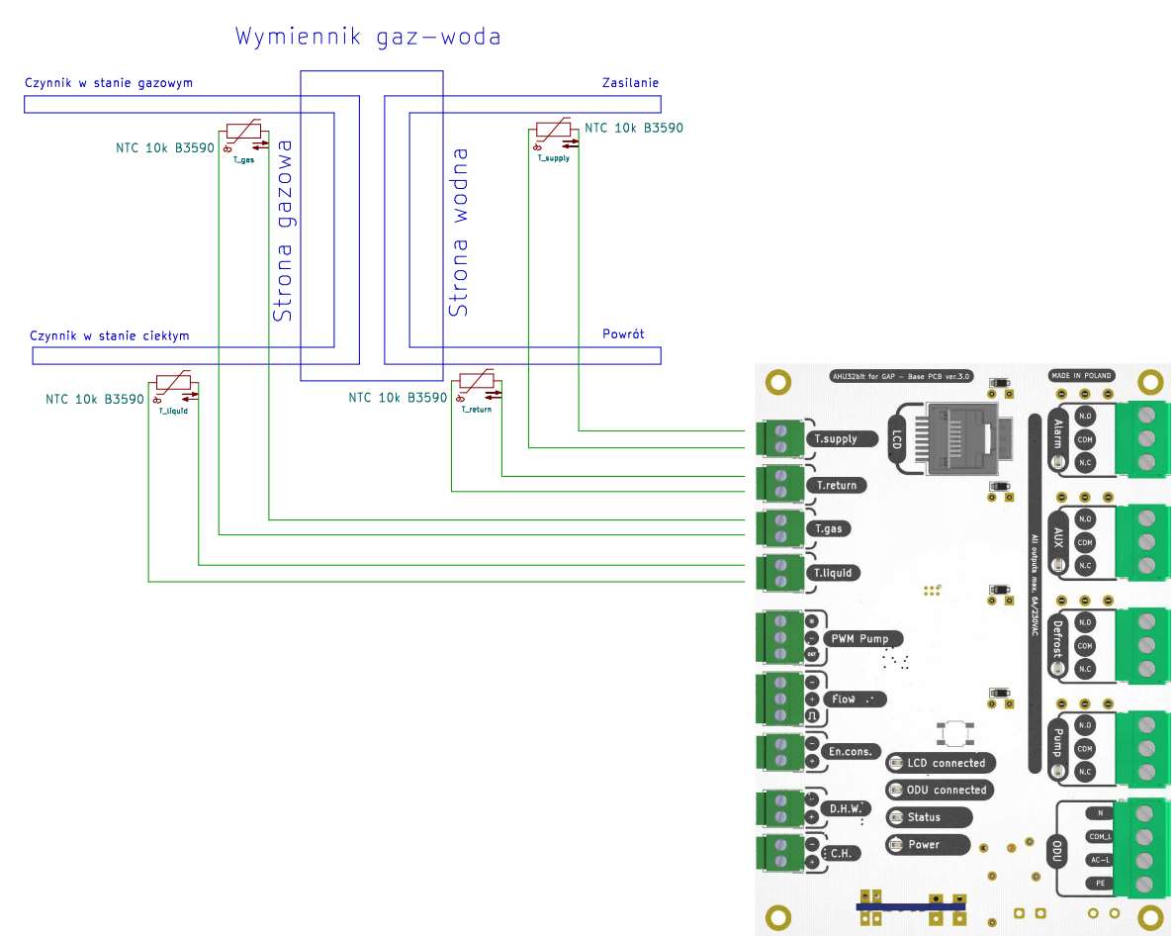
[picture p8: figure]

©2024
v1.0.0.
FabLabPro | 1 3 / 2 0

Położenie czujnika T_gas skraplacza (wymiennika gaz-woda) należy dobrać eksperymentalnie, dostosowując do posiadanego typu wymiennika.

Dla wymiennika płytowego, pracującego niskotemperaturowo (np. tylko CO, podłogówka), czujnik ten można umieścić ja rurze gazowej, blisko wymiennika.

Dla wymiennika płytowego, pracującego wysokotemperaturowo (np. CWU, grzejniki), czujnik można umieścić na obudowie, w dobranej doświadczalnie odległości od przyłączy.

ver. 1.0.1.

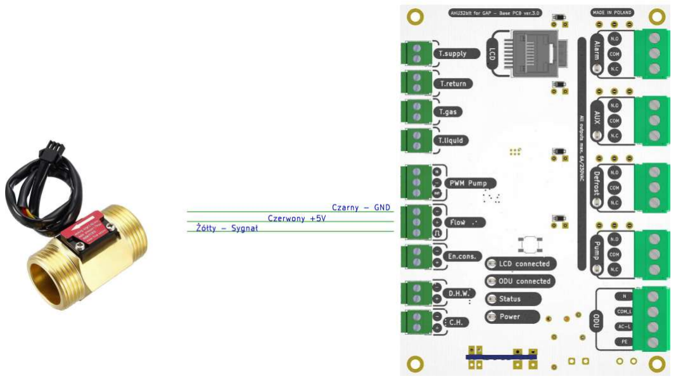
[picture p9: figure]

©2024
v1.0.0.
FabLabPro | 1 4 / 2 0

Dla wymiennika rurowego, czujnik można umieścić w doświadczalnie dobranym miejscu.

W najbardziej wymagających warunkach pracy, czujnik nie powinien wskazywać temperatury wyższej niż 55C. Powyżej tej temperatury, agregat blokuje możliwość zwiększania częstotliwości sprężarki. Powyżej ok. 58C agregat rozpoczyna obniżanie częstotliwości sprężarki, powyżej ok. 62C, następuje wyłączenie sprężarki.

Oprócz funkcji zabezpieczającej, czujnik jest wykorzystywany przez agregat do sterowania zaworu EEV.

### 6.5 Podłączenie czujnika przepływu

Sterownik AHU32bit jest przystosowany do podłączenia impulsowego czujnika przepływu typu YF-B10, lub podobnego. Napięcie zasilania czujnika wynosi 5V.

ver. 1.0.1.

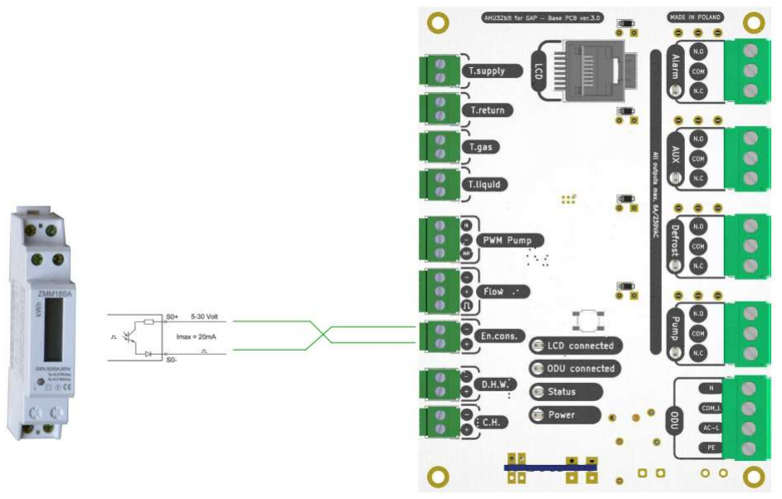
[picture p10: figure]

©2024
v1.0.0.
FabLabPro | 1 5 / 2 0

Czujnik przepływu jest konieczny do realizowania funkcji zabezpieczenia od zaniku przepływu.

Kalibracji czujnika można dokonać z poziomu menu „Ustawienia czujników”.

### 6.6 Podłączenie miernika energii

Sterownik AHU32bit jest przystosowany do podłączenia Miernika energii z wyjściem impulsowym S0. Zalecany miernik o wyjściu 2000imp/kWh.

Miernik enrgii jest konieczny do realizowania funkcji watomierza.

Kalibracji miernika można dokonać z poziomu menu „Ustawienia czujników”.

ver. 1.0.1.

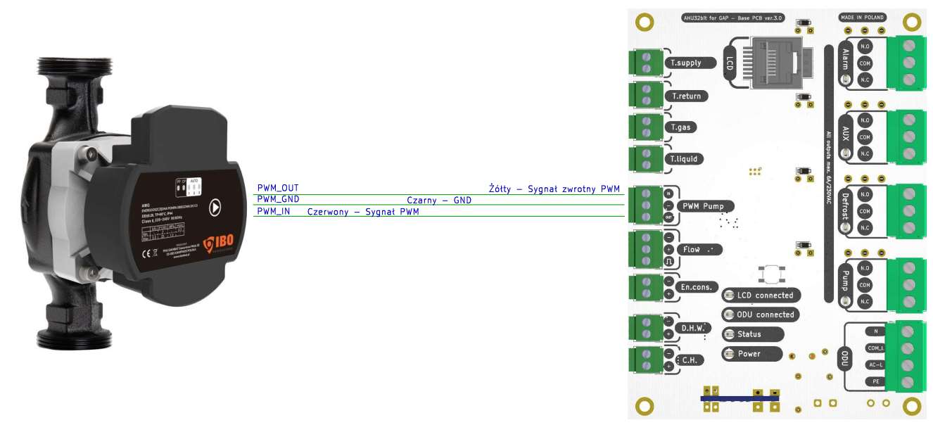
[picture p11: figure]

©2024
v1.0.0.
FabLabPro | 1 6 / 2 0

### 6.7 Podłączenie pompy obiegowej PWM

Wyjście PWM Out sterownika AHU łączymy z wejściem PWM pompy obiegowej. Wejście PWM In sterownika AHU łączymy z wyjściem PWM pompy obiegowej. Przykładowe połączenie dla pompy IBO serii AMG:

### 6.8 Podłączenie przekaźników

AHU32bit wyposażony jest w 4 wyjścia przekaźnikowe:
- Pump – do sterowania pompą obiegową
- Defrost – do sygnalizowania defrostu
- AUX – do przełączania zaworu 3D
- Alarm – do sygnalizowania błędów

UWAGA!!! Wszystkie dostępne w AHU32bit przekaźniki mają następujące parametry: 230VAC, 6A dla obciążenia rezystancyjnego. W przypadku przekroczenia któregokolwiek z parametrów, przekaźniki mogą ulec uszkodzeniu. Chcąc sterować obciążeniami o większej mocy należy użyć zewnętrznego elementu wykonawczego, a przekaźnik z AHU32bit użyć w roli elementu sterowniczego.

ver. 1.0.1.

©2024
v1.0.0.
FabLabPro | 1 7 / 2 0

Przekaźniki należy podłączać zgodnie z oznaczeniami na płytce. Dostępne są styki NO, COM oraz NC.

### 7. Uruchomienie

Sterownik AHU32bit zasilany jest z agregatu i do działania niezbędne jest poprawne połączenie między tymi elementami. Po podaniu napięcia na agregat, zasilanie trafi również do AHU32bit. Po poprawnym podłączeniu, powinna zaświecić się dioda LED „Power”. Dioda LED „Status” powinna mrugać około raz na sekundę.
Po maksymalnie 5 sekundach od podania napięcia diody LED sygnalizujące poprawną komunikację: „LCD Connected” oraz „ODU Connected” również powinny się zaświecić i pozostać zaświecone przez cały czas.
Na wyświetlaczu powinien ukazać się napis powitalny z numerem firmware. Następnie po około 0,5sek ukaże się strona główna sterownika.

### 8. Obsługa

Obsługa sterownika jest intuicyjna, dodatkowego komentarza wymaga jedynie kilka funkcji:
8.1 „Sposób sterowania” w menu „Ogólne”:
Do wyboru są dwa tryby pracy:
- „Emulacja jednostki wewnętrznej” – w tym trybie AHU32bit zachowuje się tak jak fabryczny sterownik z jednostki wewnętrznej.
- „Tryb PRO” – w tym trybie AHU32bit włącza swój wewnętrzny regulator PI i steruje proporcjonalnie pracą agregatu.
8.2 „Krzywa grzewcza” w menu „Ustawienia CO”

ver. 1.0.1.

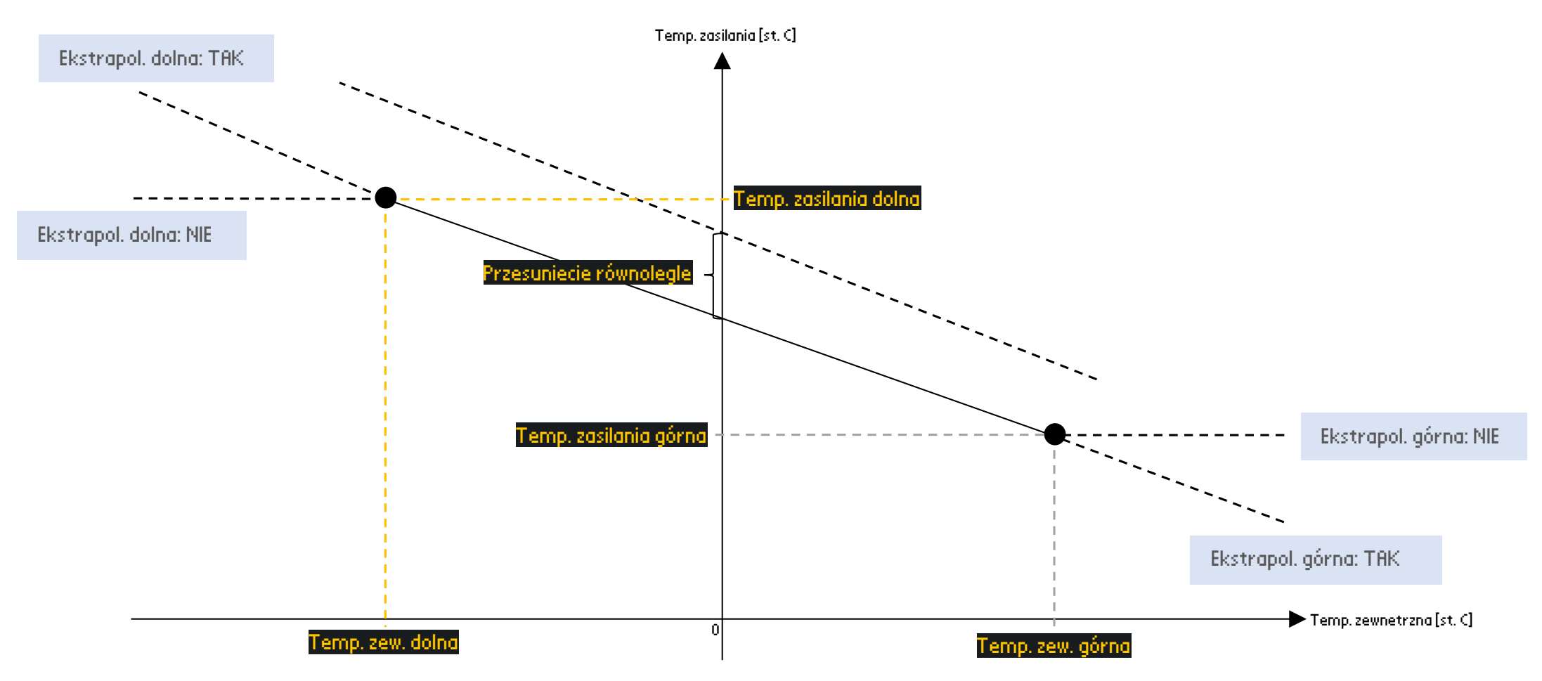
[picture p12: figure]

©2024
v1.0.0.
FabLabPro | 1 8 / 2 0

Krzywą grzewczą definiujemy podając współrzędne dwóch punktów. Pozostałe wartości zostaną obliczone przez algorytm krzywej.
Opis parametryczny krzywej grzewczej:

ver. 1.0.1.

©2024
v1.0.0.
FabLabPro | 1 9 / 2 0

8.3 „Łagodny defrost” w menu „Defrsot”
Funkcja łagodny defrost ogranicza częstotliwość pracy sprężarki podczas defrostu do zadanej wartości. Fabrycznie defrost osiąga częstotliwość 85Hz+.

W przypadku przekroczenia częstotliwości defrost zostanie przerwane, ponowny defrost wywoływany jest po przerwie około 3 min. Defrost jest powtarzany, do momentu osiągnięcia temperatury 20C na parowniku.

8.4 „Wymuś defrost” w menu „Defrost”
Funkcja wymuś defrost wymusza przeprowadzenie defrostu, niezależnie od stanu systemu.

Uwaga! Po wywołaniu funkcji, funkcja defrostu pozostanie aktywna do momentu jej wyłączenia w menu lub do momentu wyłączenia sterownika AHU32bit.

### 8.5 Strojenie regulatorów CO i CWU

Ważne!

Strojenie należy przeprowadzać bez pospiechu. Cechą dużych obiektów ciepłych jest spora bezwładność. Strojąc układ należy zmieniać w jednym kroku tylko jedna nastawię. Kolejna korektę należy wprowadzić dopiero po ustabilizowaniu się systemu.

Zwiększając stałą proporcjonalną kp oraz stałą całkującą ki regulator staje się szybszy i bardziej responsywny na zmiany temperatury. Nadmierne zwiększenie stałych może doprowadzić do rozchwiania systemu i pojawienia się oscylacji. Poprawnie nastrojony układ powinien utrzymywać zadaną temperaturę w zakresie +/-1.5C

ver. 1.0.1.

©2024
v1.0.0.
FabLabPro | 2 0 / 2 0

### 9. Gwarancja

Dostarczone części są objęte gwarancją. Producent nie bierze natomiast odpowiedzialności za montaż oraz instalację układu oraz pracę całego systemu. Okres gwarancji wynosi 1 rok od daty sprzedaży.

### 10. Słowniczek

ODU – Outdoor Unit – jednostka zewnętrzna, agregat.
LCD – Liquid crystal display, wyświetlacz
LED – light emmiting diode, dioda świecąca
Firmware – oprogramowanie układowe
T_supply – temperature zasilana
T_return – tempreatura powrotu
T_gas – tempreatura rury gazowej
T_liquid – temperature rury cieczowej
Flow – przepływ
En. cons. (Energy consumed) – energia konsumowana

### 11. Producent

FabLabPro
Wyprodukowano w Polsce
Wszystkie prawa zastrzeżone.

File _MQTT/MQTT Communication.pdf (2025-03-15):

Lp. | MQTT Topic | Opis | Jednostka
2 | AHU32bit/realtime/def_power_state | Stan załączenia sterownika | 0-OFF | 1-ON | -
3 | AHU32bit/realtime/IN_CH_ON | Wejście CO | 0-OFF | 1-ON | -
4 | AHU32bit/realtime/IN_DHW_ON | Wejście CWU | 0-OFF | 1-ON | -
5 | AHU32bit/realtime/Compressor_command | Częstotliwość zadana | | | Hz
6 | AHU32bit/realtime/def_actual_freq | Częstotliwość aktualna | | | Hz
7 | AHU32bit/realtime/def_actual_dc_voltage | Napięcie DC | | | V
8 | AHU32bit/realtime/def_actual_current | Prąd AC | | | A
9 | AHU32bit/realtime/def_on_off_counter | Ilość załączeń | | | x
10 | AHU32bit/realtime/def_operation_time | Łączny czas pracy | | | h
11 | AHU32bit/realtime/Temp_Set_Command | Temp. zadana | | | °C
12 | AHU32bit/realtime/Temp_Set_Command_CH | Temp. zadana CO | | | °C
13 | AHU32bit/realtime/def_DHW_set_value | Temp. zadana CWU | | | °C
14 | AHU32bit/realtime/Temp_Supply | Temp. zasilanie | | | °C
15 | AHU32bit/realtime/Temp_Return | Temp. powrót | | | °C
16 | AHU32bit/realtime/Temp_Gas | Temp. gaz | | | °C
17 | AHU32bit/realtime/Temp_Liquid | Temp. ciecz | | | °C
18 | AHU32bit/realtime/Temp_Room | Temp. pokojowa | | | °C
19 | AHU32bit/realtime/def_Temp_Out | Temp. zewnętrzna | | | °C
20 | AHU32bit/realtime/def_Temp_Cond | Temp. parownik | | | °C
21 | AHU32bit/realtime/def_Temp_Disch | Temp. sprężarka | | | °C
22 | AHU32bit/realtime/def_Temp_Module | Temp. falownik | | | °C
23 | AHU32bit/realtime/power_consumed | Moc pobrana | | | W
24 | AHU32bit/realtime/power_produced | Moc oddana | | | W
25 | AHU32bit/realtime/P_COP | P COP | | | x
26 | AHU32bit/realtime/energy_CH_consumed | E CO pobrana | | | kWh
27 | AHU32bit/realtime/energy_CH_produced | E CO oddana | | | kWh
28 | AHU32bit/realtime/E_CH_COP | E CO COP | | | x
29 | AHU32bit/realtime/energy_DWH_consumed | E CWU pobrana | | | kWh
30 | AHU32bit/realtime/energy_DWH_produced | E CWU oddana | | | kWh
31 | AHU32bit/realtime/E_DWH_COP | E CWU COP | | | x
32 | AHU32bit/realtime/actual_flow | Przepływ | | | l/h
33 | AHU32bit/realtime/def_defrost_counter | Ilość defrostów | | | x
34 | AHU32bit/realtime/under_defrost_flag | Aktualnie pod defrostem (flaga) | 0-NIE | 1-TAK | -
35 | AHU32bit/realtime/OUT_Pump_REQUEST | Pompa obiegowa | 0-OFF | 1-ON | -
36 | AHU32bit/realtime/PWM_pump_duty | PWM out | | | %
37 | AHU32bit/realtime/PWM_in_duty | PWM in | | | %
38 | AHU32bit/realtime/def_delta_command | Zadana delta | | | °C
39 | AHU32bit/realtime/Temp_delta | Aktualna delta | | | °C
40 | AHU32bit/realtime/actual_EEV | EEV | | | krok
41 | AHU32bit/realtime/actual_EEV_A | EEV-A | | | krok
42 | AHU32bit/realtime/actual_EEV_B | EEV-B | | | krok
43 | AHU32bit/realtime/def_actual_ODU_fan | Went. ODU | | | rpm
44 | AHU32bit/realtime/raw_pulses_Flow | Przepływ RAW | | | -
45 | AHU32bit/realtime/def_power_lock | Blok. zał. | 0-NIE | 1-TAK | -
46 | AHU32bit/realtime/ODU_type | Typ ODU | | | -
47 | AHU32bit/realtime/oil_recovery_flag | Flaga olejowania | 0-NIE | 1-TAK | -
48 | AHU32bit/realtime/gas_recovery_flag | Flaga odzysku czynnika | 0-NIE | 1-TAK
49 | AHU32bit/realtime/def_weather_curve | Flaga krzywej grzewczej | 0-NIE | 1-TAK
50 | AHU32bit/realtime/LCD_state_BYTE | State_byte
51 | AHU32bit/realtime/CH_active_flag | Flaga wyłączenia od temp. zew. | 0-NIE | 1-TAK
52 | AHU32bit/realtime/LCD_firmware_MAJOR | Wersja LCD firmware_MAJOR
53 | AHU32bit/realtime/LCD_firmware_MINOR | Wersja LCD firmware_MINOR
54 | AHU32bit/realtime/LCD_firmware_PATCH | Wersja LCD firmware_PATCH
55 | AHU32bit/realtime/def_custom_defrost_activeIndywidualny defrost załączony | | 0-TAK | 1-NIE
56
57 | AHU32bit/realtime/under_custom_defrost_flagAktualnie pod indywidualnym defrostem (flaga) 0-NIE | | | 1-TAK
58 | AHU32bit/realtime/custom_defrost_trigg_countdown Oliczanie do kolejnego defrostu | | | | sek.
59 | AHU32bit/realtime/custom_defrost_finish_countdown Odliczanie do zakończenia defrostu | | | | sek.
60 | AHU32bit/realtime/def_Temp_Cond_2 | Temp. parownik 2 | | | °C
61 | AHU32bit/realtime/def_parallel_shift | Przesunięcie równoległe krzywej pogodowej | | | °C
62 | AHU32bit/realtime/keypad_locked | Blokada klawiatury | 0-TAK | 1-NIE
63 | AHU32bit/realtime/IDU_alarm_byte_1 | Alarm AHU 1
64 | AHU32bit/realtime/ODU_alarm_byte_3 | Alarm ODU 1
65 | AHU32bit/realtime/ODU_alarm_byte_4 | Alarm ODU 2
66 | AHU32bit/realtime/ODU_alarm_byte_5 | Alarm ODU 3
67 | AHU32bit/realtime/ODU_alarm_byte_6 | Alarm ODU 4
68 | AHU32bit/realtime/ODU_alarm_byte_7 | Alarm ODU 5
69 | AHU32bit/realtime/ODU_alarm_byte_8 | Alarm ODU 6
70 | AHU32bit/realtime/def_state_BYTE_1 | ODU_state_BYTE_1
71 | AHU32bit/realtime/def_state_BYTE_2 | ODU_state_BYTE_2
72 | AHU32bit/realtime/def_state_BYTE_3 | ODU_state_BYTE_3
73 | AHU32bit/realtime/def_Contorl_Mode | Tryb pracy | 0-Emulacja | 1-Tryb PRO
74 AHU32bit/realtime/command_ODU_fan
73 | AHU32bit/controls/on_off_command | 0-OFF | 1-ON
74 AHU32bit/controls/temp_command | | 0-pomniejsz temperature o jedną jednostkę (decr) | 1-powiększ temperaturę o jedną jednostkę (decr)

Wartość
Publikacje MQTT (pub)

Subskrybcje MQTT (sub)

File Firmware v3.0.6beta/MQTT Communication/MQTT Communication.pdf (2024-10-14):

Lp. | MQTT Topic | Opis
1 | AHU32bit/realtime/def_power_state | Stan sterownika
2 | AHU32bit/realtime/IN_CH_ON | Wejście CO
3 | AHU32bit/realtime/IN_DHW_ON | Wejście CWU
4 | AHU32bit/realtime/Compressor_command | Częstotliwość zadana
5 | AHU32bit/realtime/def_actual_freq | Częstotliwość aktualna
6 | AHU32bit/realtime/def_actual_dc_voltage | Napięcie DC
7 | AHU32bit/realtime/def_actual_current | Prąd AC
8 | AHU32bit/realtime/def_on_off_counter | Ilość załączeń
9 | AHU32bit/realtime/def_operation_time | Łączny czas pracy
10 | AHU32bit/realtime/Temp_Set_Command | Temp. zadana
11 | AHU32bit/realtime/Temp_Set_Command_CH | Temp. zadana CO
12 | AHU32bit/realtime/def_DHW_set_value | Temp. zadana CWU
13 | AHU32bit/realtime/Temp_Supply | Temp. zasilanie
14 | AHU32bit/realtime/Temp_Return | Temp. powrót
15 | AHU32bit/realtime/Temp_Gas | Temp. gaz
16 | AHU32bit/realtime/Temp_Liquid | Temp. ciecz
17 | AHU32bit/realtime/Temp_Room | Temp. pokojowa
18 | AHU32bit/realtime/def_Temp_Out | Temp. zewnętrzna
19 | AHU32bit/realtime/def_Temp_Cond | Temp. cond.
20 | AHU32bit/realtime/def_Temp_Disch | Temp. disch.
21 | AHU32bit/realtime/def_Temp_Module | Temp. modul.
22 | AHU32bit/realtime/power_consumed | Moc pobrana
23 | AHU32bit/realtime/power_produced | Moc oddana
24 | AHU32bit/realtime/P_COP | P COP
25 | AHU32bit/realtime/energy_CH_consumed | E CO pobrana
26 | AHU32bit/realtime/energy_CH_produced | E CO oddana
27 | AHU32bit/realtime/E_CH_COP | E CO COP
28 | AHU32bit/realtime/energy_DWH_consumed | E CWU pobrana
29 | AHU32bit/realtime/energy_DWH_produced | E CWU oddana
30 | AHU32bit/realtime/E_DWH_COP | E CWU COP
31 | AHU32bit/realtime/actual_flow | Przepływ
32 | AHU32bit/realtime/def_defrost_counter | Ilość defrostów
33 | AHU32bit/realtime/under_defrost_flag | Aktualnie pod defrostem
34 | AHU32bit/realtime/OUT_Pump_REQUEST | Pompa obiegowa
35 | AHU32bit/realtime/PWM_pump_duty | PWM out
36 | AHU32bit/realtime/PWM_in_duty | PWM in
37 | AHU32bit/realtime/def_delta_command | Zadana delta
38 | AHU32bit/realtime/Temp_delta | Aktualna delta
39 | AHU32bit/realtime/actual_EEV | EEV
40 | AHU32bit/realtime/actual_EEV_A | EEV-A
41 | AHU32bit/realtime/actual_EEV_B | EEV-B
42 | AHU32bit/realtime/def_actual_ODU_fan | Went. ODU
43 | AHU32bit/realtime/raw_pulses_Flow | Przepływ RAW
44 | AHU32bit/realtime/def_power_lock | Blok. zał.
45 | AHU32bit/realtime/ODU_type | Typ ODU
46 | AHU32bit/realtime/oil_recovery_flag | Flaga olejowania
47 | AHU32bit/realtime/gas_recovery_flag | Flaga odzysku czynnika
48 | AHU32bit/realtime/def_weather_curve | Flaga krzywej grzewczej
49 | AHU32bit/realtime/LCD_state_BYTE | State_byte
50 | AHU32bit/realtime/CH_active_flag | Flaga wyłączenia od temp. zew.

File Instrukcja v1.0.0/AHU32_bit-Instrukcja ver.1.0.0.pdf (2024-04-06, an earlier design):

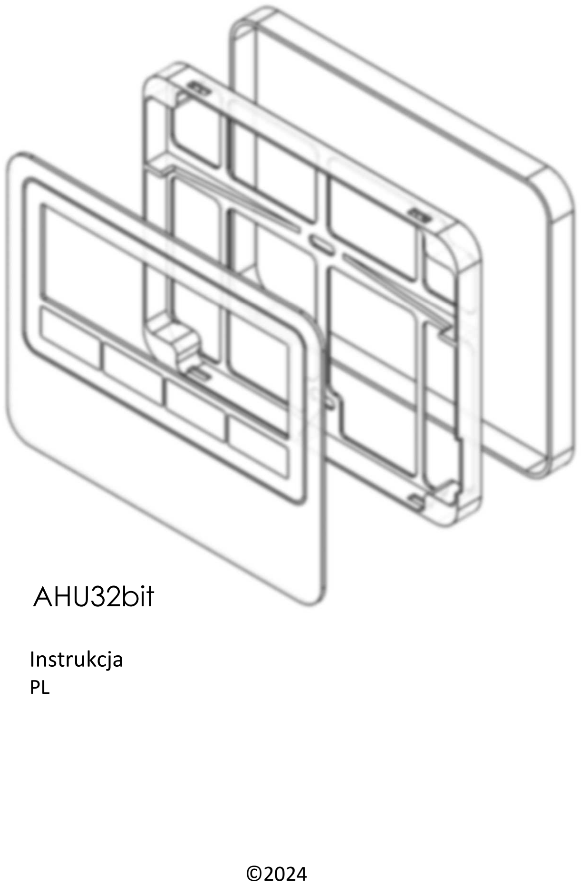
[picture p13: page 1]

©2024

AHU32bit

### Instrukcja

PL

FabLabPro
ver. 1.0.0.

©2024
v1.0.0.
FabLabPro | 2 / 1 9

## Spis treści:

ver. 1.0.0.

©2024
v1.0.0.
FabLabPro | 3 / 1 9

### 1. Wstęp

Dziękujemy za zakup sterownika AHU32bit. Niniejsza instrukcja pokaże jak zamontować i uruchomić sterownik w poprawny i bezpieczny sposób. Dopełniliśmy wszelkich starań, aby jego instalacja sprawiła wiele przyjemności, a efekt cieszył oko przez długi czas. W razie jakichkolwiek pytań, czy uwag prosimy się zgłaszać pod adres e-mail: ciackamichal@gmail.com. Chcąc być na bieżąco z
aktualizacjami | oraz | wiadomościami | subskrybuj | media
społecznościowe projektu:
| AHU32bit
| AHU32bit
| #AHU32bit
Pompa ciepła - OPEN SOURCE Projekt sterowania i monitoringu w jednym
POMPA CIEPŁA

JAK ZROBIĆ

FORUM

### 2. Zawartość zestawu

W jego skład wchodzą:
- Zmontowana płytka drukowana LCD (1 szt.)
- Zmontowana płytka drukowana Bazowa (1 szt.) z wtyczkami
- Kołki montażowe do płytki BAZA (4 szt.)
- Ramka montażowa do płytki LCD (1 szt.) - GRATIS
- Czujniki temperatury typu NTC 10k B3950 (4 szt.)
- Izolacja termokurczliwa z oznaczeniami czujników (8 szt.)
- Kabel 1m typu Ethernet RJ45 (1 szt.)

ver. 1.0.0.

©2024
v1.0.0.
FabLabPro | 4 / 1 9

### 3. Podstawowe cechy

Ważne!
Sterownik jest przeznaczony do wbudowania w istniejący system grzewczy z pompa ciepła. Sterownik nie jest przeznaczony do pracy poza systemem grzewczym!
Sterownik AHU32bit to urządzenie umożliwiające sterownie prestiżowymi
agregatami powietrznymi. AHU32bit zastępuje jednostkę wewnętrzną. Podstawowym zadaniem AHU32bit jest stabilizacja temperatury zasilania systemu grzewczego na zadanym poziomie. Możliwy jest wybór temperatury grzania za pomocą wejść bezpotencjałowych, osobno dla CO i CWU.
Uwaga! Do pełnej pracy w trybie CWU niezbędny jest sterownik (termostat) załączający zawór 3D oraz ewentualni dodatkową pompę.
Stabilizacja jest w pełni proporcjonalna i w zakresie modulacji instalacji.
Zadana wartość temperatury może pochodzić z krzywej grzewczej lub mieć stałą wartość.
Właściwości:
- Duży, czytelny wyświetlacz graficzny (4.5”).
- Przyciski dotykowe.
- Tryb Lato/zima.
- Krzywa pogodowa.
- Podgląd wszystkich parametrów dostępnych w systemie:
- Temperatury: zasilania, powrotu, gazu, cieczy, zewnętrznej, parownika, sprężarki, falownika,
- Parametry pracy sprężarki: częstotliwość, moc elektryczna (konsumowana), energia elektryczna (konsumowana), prąd AC, napięcie DC.
- Wysterowanie EEV,

ver. 1.0.0.

©2024
v1.0.0.
FabLabPro | 5 / 1 9
- Obroty wentylatora jednostki zewnętrznej,
- Funkcje statystyczne:
- Ilość załączeń sprężarki,
- Ilość defrostów,
- Łączny czas pracy sprężarki
- Wyjścia przekaźnikowe:
- Sygnalizacja defrostu,
- Alarm,
- Pompa obiegowa,
- AUX (docelowo do sterownia biwalentnego).
- Zabezpieczenia:
- Zaniku przepływu,
- Spadku temperatury,
- Błędu czujnika.
- Sterowanie pogodowe

### 4. Niezbędne narzędzia i materiały do montażu

Zakładamy, że osoba montująca sterownik AHU32bit posiada zaawansowaną wiedzę i umiejętności w zakresie pomp ciepła oraz elektryki. Płytkę bazową sterownika należy zabudować w szczelnej szafie sterowniczej. Płytkę wyświetlacza LCD zamontować na zewnątrz szafy sterowniczej w dostępnym miejscu. Z elementami sterownika należy się obchodzić delikatnie.
Niezbędne narzędzia:
✓ | Mały wkrętak płaski (max. 3mm)
✓ | Przewód do przedłużenia czujników temperatury (doskonale
| nadaje się skrętka internetowa, ma akurat 4 skręcone pary
| przewodów). Długość przewodów należy dostosować do
| własnej instalacji.

ver. 1.0.0.

©2024
v1.0.0.
FabLabPro | 6 / 1 9
✓ | Złączki lub lutownica i cyna do połączenia przewodów z
| czujnikami

Może się również przydać:

✓ | Wiertarka
✓ | Wiertła
✓ | Praska do zaciskania tulejek na przewodach

### 5. Montaż mechaniczny

Płytkę bazową należy zamontować w szafce sterowniczej tak, aby zapewnić swobodny dostęp do złącz. W przypadku montażu na płycie montażowej, można do tego celu użyć kołków montażowych dostarczonych w zestawie.

UWAGA!!! W sterowniku, podczas pracy występuje napięcie niebezpieczne dla zdrowia i życia człowieka. Montaż oraz podłączenie należy przeprowadzić ze szczególną ostrożnością, przy wyłączonym napięciu!

ver. 1.0.0.

©2024
v1.0.0.

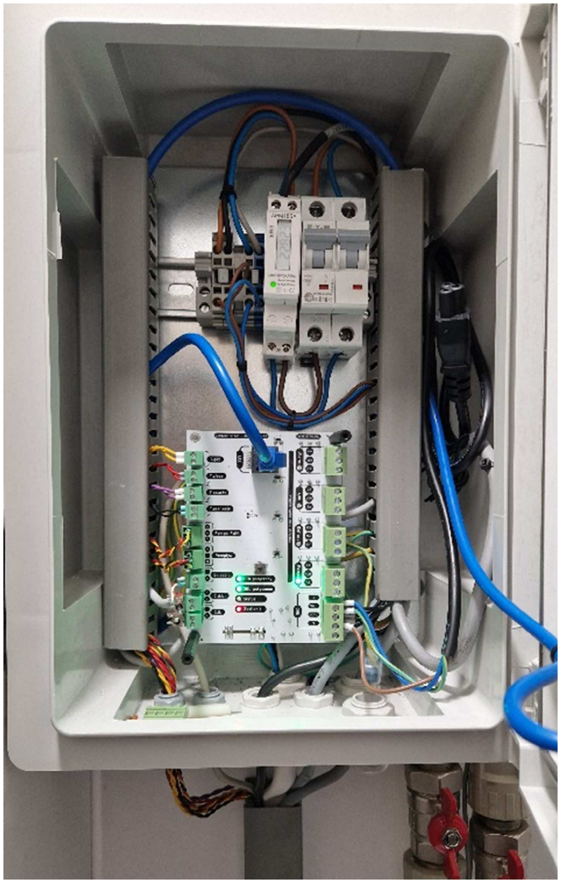
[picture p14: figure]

FabLabPro | 7 / 1 9

Płytkę LCD można zamontować na elewacji za pomocą dostarczonej w zestawie ramki montażowej. Ramka jest też przystosowana do montażu ze standardową puszką instalacyjną 60mm.

ver. 1.0.0.

©2024
v1.0.0.

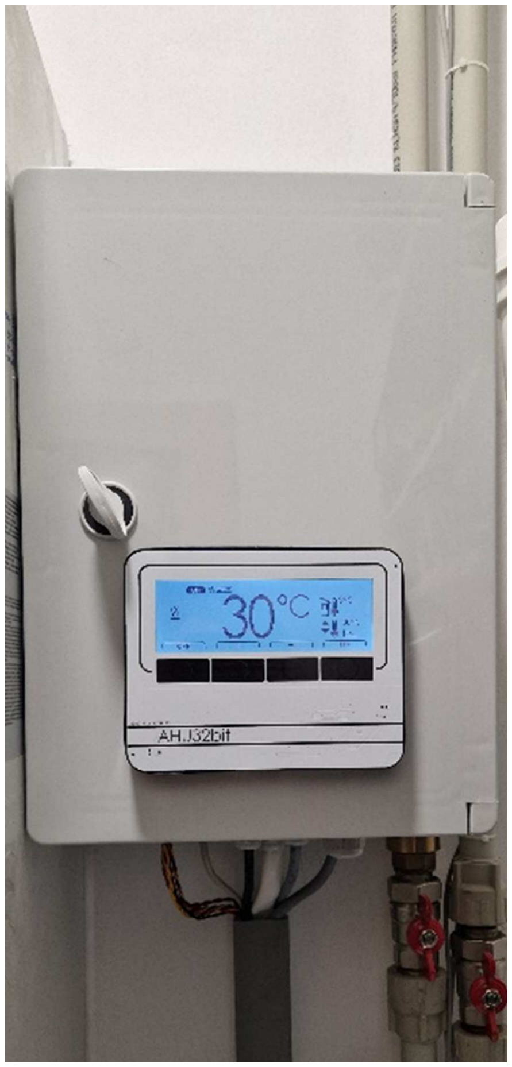
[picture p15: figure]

FabLabPro | 8 / 1 9

Po montażu można zdjąć folie ochronne na ekranie oraz ramce montażowej.

### 6. Podłączenie

### 6.1 Podłączenie sygnału żądania grzania CO i CWU

Aby sterownik rozpoczął pracę konieczne jest podanie sygnału zewnętrznego na bezpotencjałowe wejście żądania grzania CO lub CWU.

W klasycznej aplikacji na wejściu żądania CO należy wykonać zworę, a do wejścia żądania grzania CWU naley podłączyć termostat.

ver. 1.0.0.

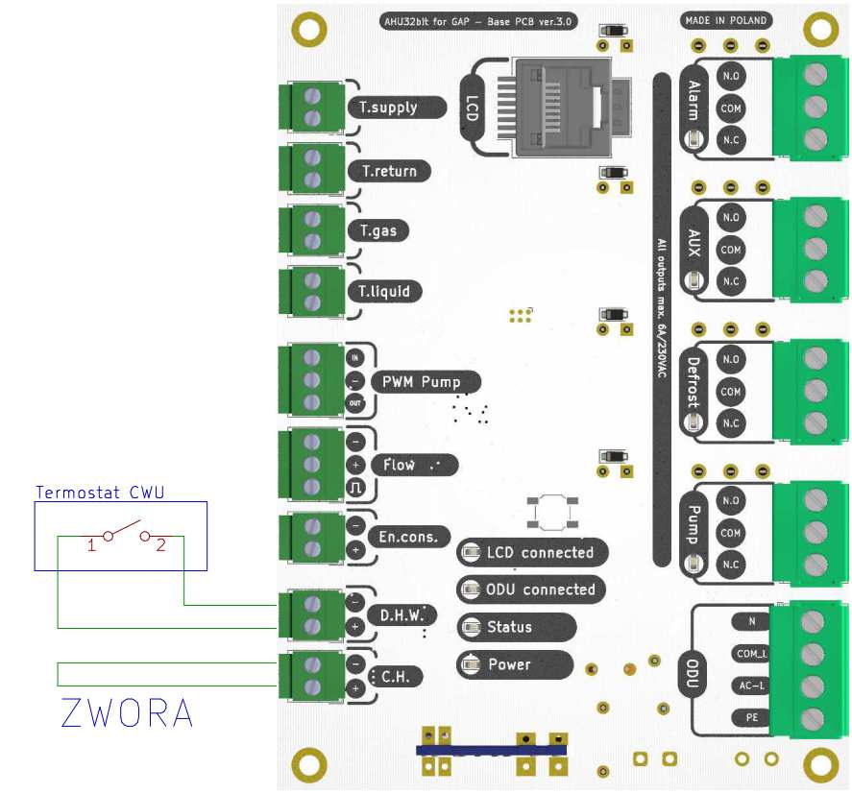
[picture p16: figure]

©2024
v1.0.0.
FabLabPro | 9 / 1 9

Termostat CWU należy podłączyć zgodnie z zaleceniami producenta. Należy pamiętać, że wejście żądania grzania CWU w AHU32bit jest bezpotencjałowe.

Uwaga! Pojawienie się potencjału na wejściu żądania grzania CO oraz CWU uszkodzi sterownik!

### 6.2 Podłączenie zasilania i komunikacji z agregatem

Podłączenie zasilania i komunikacji z agregatem dokonujemy identycznie jak dla fabrycznej jednostki wewnętrznej.

ver. 1.0.0.

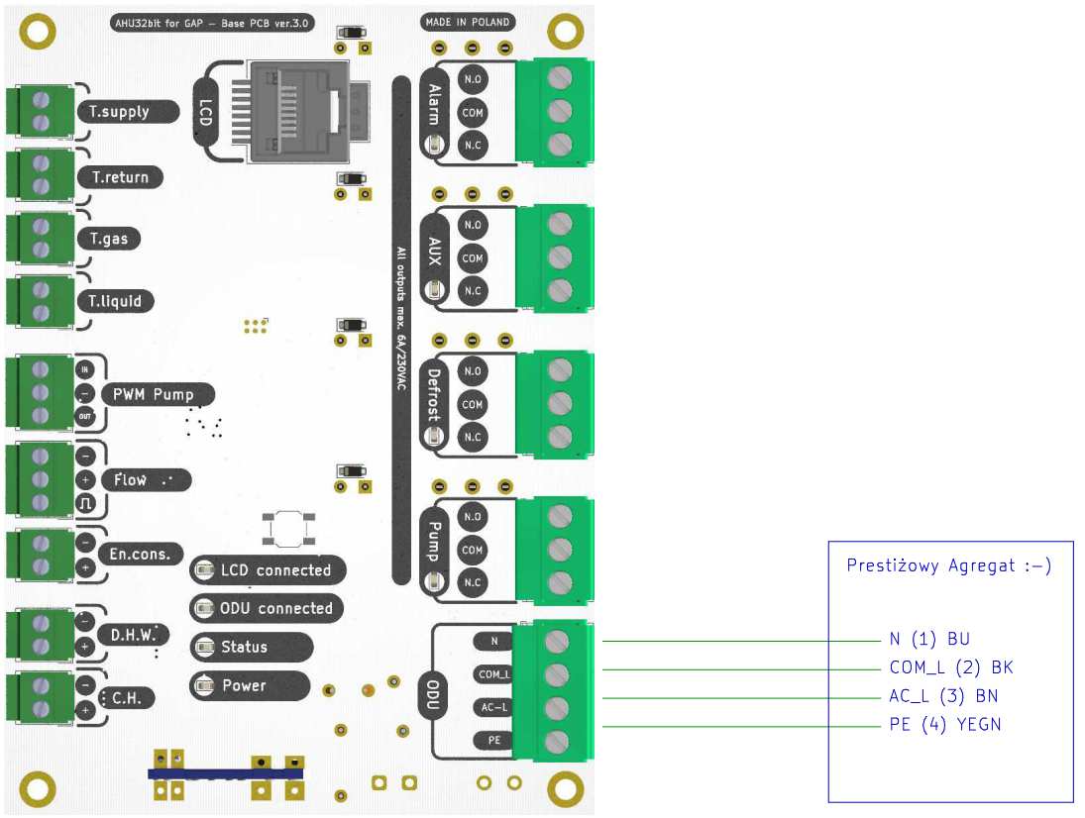
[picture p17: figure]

©2024
v1.0.0.
FabLabPro | 1 0 / 1 9

### 6.3 Podłączenie z wyświetlaczem LCD

Połączenie miedzy płytką Bazową, a płytką LCD należy dokonać za pomocą dołączonego do zestawu przewodu zgodnego ze standardem Ethernet (skrętka RJ45).

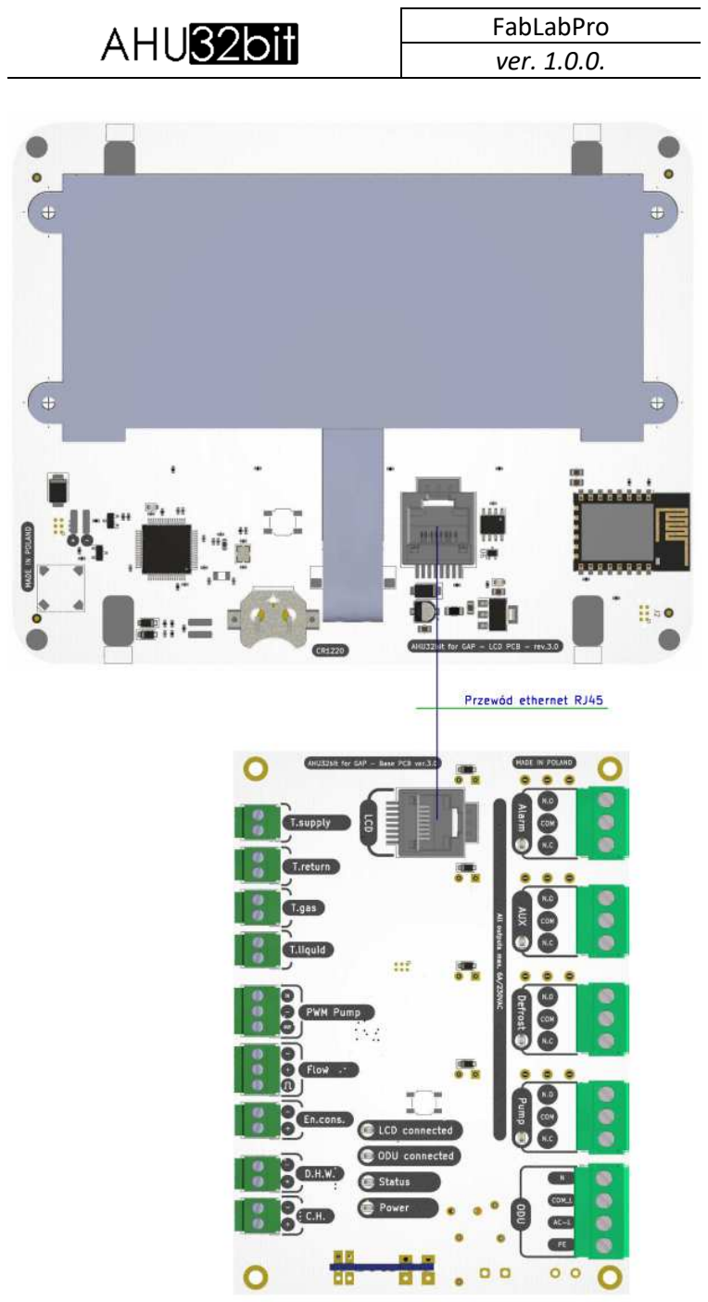
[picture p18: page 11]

ver. 1.0.0.

©2024
v1.0.0.
FabLabPro | 1 1 / 1 9

ver. 1.0.0.

©2024
v1.0.0.
FabLabPro | 1 2 / 1 9

W przypadku oddalenia płytki LCD od płytki Bazowej ponad 1m połączenie należy wykonać we własnym zakresie.
Uwaga! Płytka LCD jest zasilana tym przewodem! Należy stosować dobrej jakości skrętkę miedzianą, aby zniwelować spadki napięcia na przewodzie.

### 6.4 Podłączenie czujników temperatury

Ważne!
Prawidłowe zamontowanie czujnika na zasilaniu oraz czujnika na rurze gazowej jest kluczowe do prawidłowej pracy systemu!

AHU32bit współpracuje z termistorami typu NTC 10k B3950.
Tam gdzie jest to możliwe, zalecane jest montowanie czujników temperatury z użyciem kapilar. W przypadku niemożliwości zastosowania kapilar, należy czujnik solidnie zamontować do powierzchni mierzonego elementu za pomocą taśm izolacyjnych i opasek zaciskowych.

ver. 1.0.0.

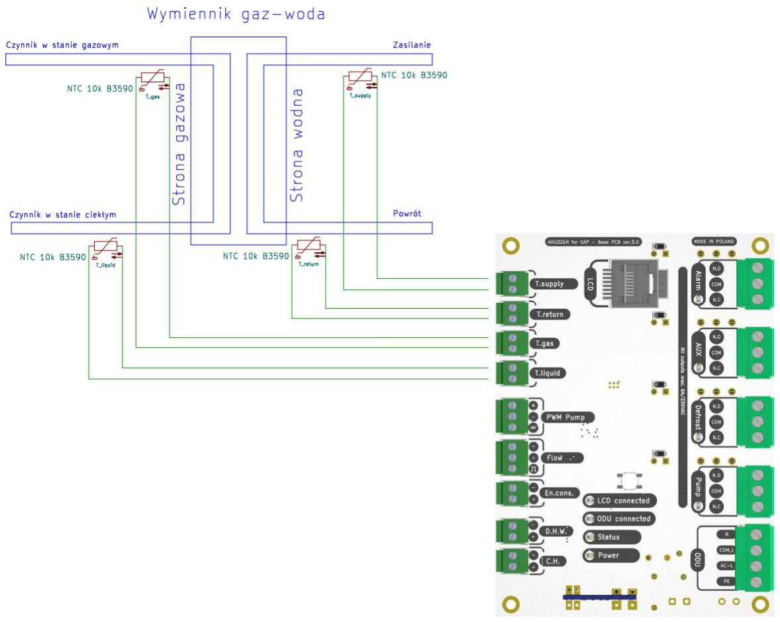
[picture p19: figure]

©2024
v1.0.0.
FabLabPro | 1 3 / 1 9

Położenie czujnika T_gas skraplacza (wymiennika gaz-woda) należy dobrać eksperymentalnie, dostosowując do posiadanego typu wymiennika.

Dla wymiennika płytowego, pracującego niskotemperaturowo (np. tylko CO, podłogówka), czujnik ten można umieścić ja rurze gazowej, blisko wymiennika.

Dla wymiennika płytowego, pracującego wysokotemperaturowo (np. CWU, grzejniki), czujnik można umieścić na obudowie, w dobranej doświadczalnie odległości od przyłączy.

ver. 1.0.0.

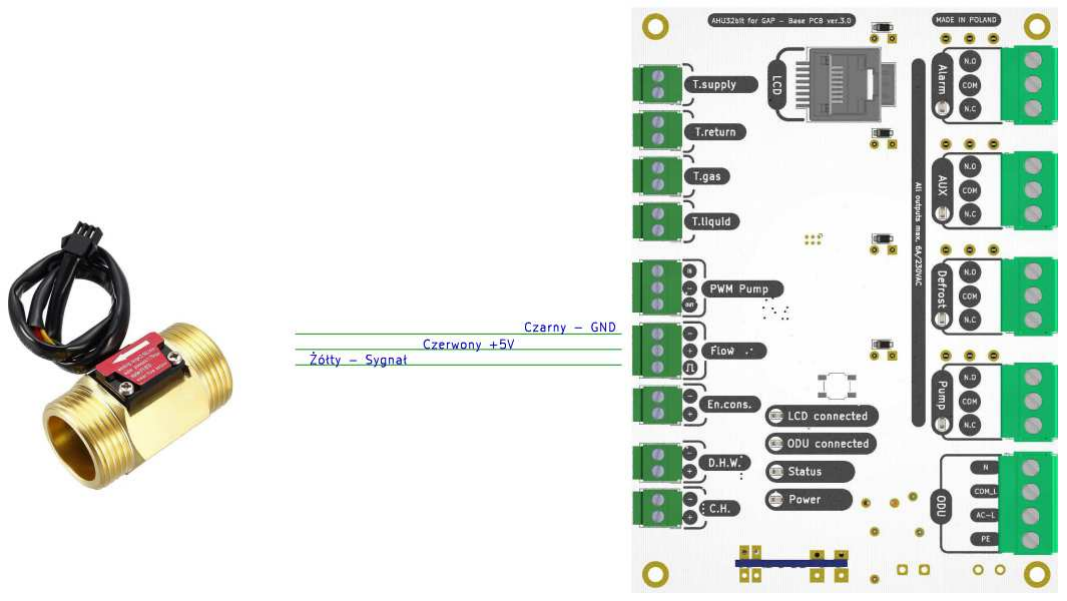
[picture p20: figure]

©2024
v1.0.0.
FabLabPro | 1 4 / 1 9

Dla wymiennika rurowego, czujnik można umieścić w doświadczalnie dobranym miejscu.

W najbardziej wymagających warunkach pracy, czujnik nie powinien wskazywać temperatury wyższej niż 55°C. Powyżej tej temperatury, agregat blokuje możliwość zwiększania częstotliwości sprężarki. Powyżej ok. 58°C agregat rozpoczyna obniżanie częstotliwości sprężarki, powyżej ok. 62°C, następuje wyłączenie sprężarki.

Oprócz funkcji zabezpieczającej, czujnik jest wykorzystywany przez agregat do sterowania zaworu EEV.

### 6.5 Podłączenie czujnika przepływu

Sterownik | AHU32bit | jest | przystosowany | do | podłączenia
impulsowego czujnika przepływu typu YF-B10, lub podobnego. Napięcie zasilania czujnika wynosi 5V.

ver. 1.0.0.

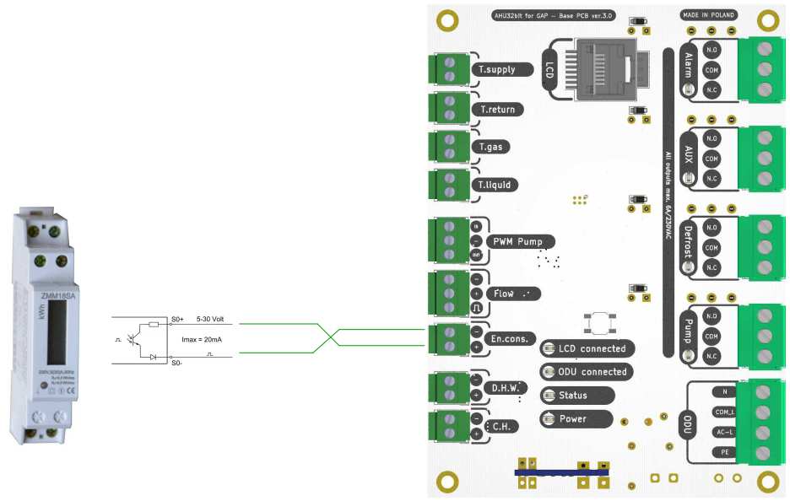
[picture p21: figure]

©2024
v1.0.0.
FabLabPro | 1 5 / 1 9

Czujnik przepływu jest konieczny do realizowania funkcji zabezpieczenia od zaniku przepływu.

Kalibracji czujnika można dokonać z poziomu menu „Ustawienia czujników”.

### 6.6 Podłączenie miernika energii

Sterownik AHU32bit jest przystosowany do podłączenia Miernika energii z wyjściem impulsowym S0. Zalecany miernik o wyjściu 2000imp/kWh.

Miernik enrgii jest konieczny do realizowania funkcji watomierza.

Kalibracji miernika można dokonać z poziomu menu „Ustawienia czujników”.

ver. 1.0.0.

©2024
v1.0.0.
FabLabPro | 1 6 / 1 9

### 6.7 Podłączenie pompy PWM

Niedostępne w wersji firmware ver.1.0.0.

### 6.8 Podłączenie przekaźników

AHU32bit wyposażony jest w 4 wyjścia przekaźnikowe:
- Pump – do sterowania pompą obiegową
- Defrost – do sygnalizowania defrostu
- AUX – do przełączania zaworu 3D
- Alarm – do sygnalizowania błędów
Przekaźniki należy podłączać zgodnie z oznaczeniami na płytce. Dostępne są styki NO, COM oraz NC.

### 7. Uruchomienie

Sterownik AHU32bit zasilany jest z agregatu i do działania niezbędne jest poprawne połączenie między tymi elementami. Po podaniu napięcia na agregat, zasilanie trafi również do AHU32bit. Po poprawnym podłączeniu, powinna zaświecić się dioda LED „Power”. Dioda LED „Status” powinna mrugać około raz na sekundę.
Po maksymalnie 5 sekundach od podania napięcia diody LED sygnalizujące poprawną komunikację: „LCD Connected” oraz „ODU Connected” również powinny się zaświecić i pozostać zaświecone przez cały czas.
Na wyświetlaczu powinien ukazać się napis powitalny z numerem firmware. Następnie po około 0,5sek ukaże się strona główna sterownika.

UWAGA!!! Wszystkie dostępne w AHU32bit przekaźniki mają następujące parametry: 230VAC, 6A dla obciążenia rezystancyjnego. W przypadku przekroczenia któregokolwiek z parametrów, przekaźniki mogą ulec uszkodzeniu. Chcąc sterować obciążeniami o większej mocy należy użyć zewnętrznego elementu wykonawczego, a przekaźnik z AHU32bit użyć w roli elementu sterowniczego.

ver. 1.0.0.

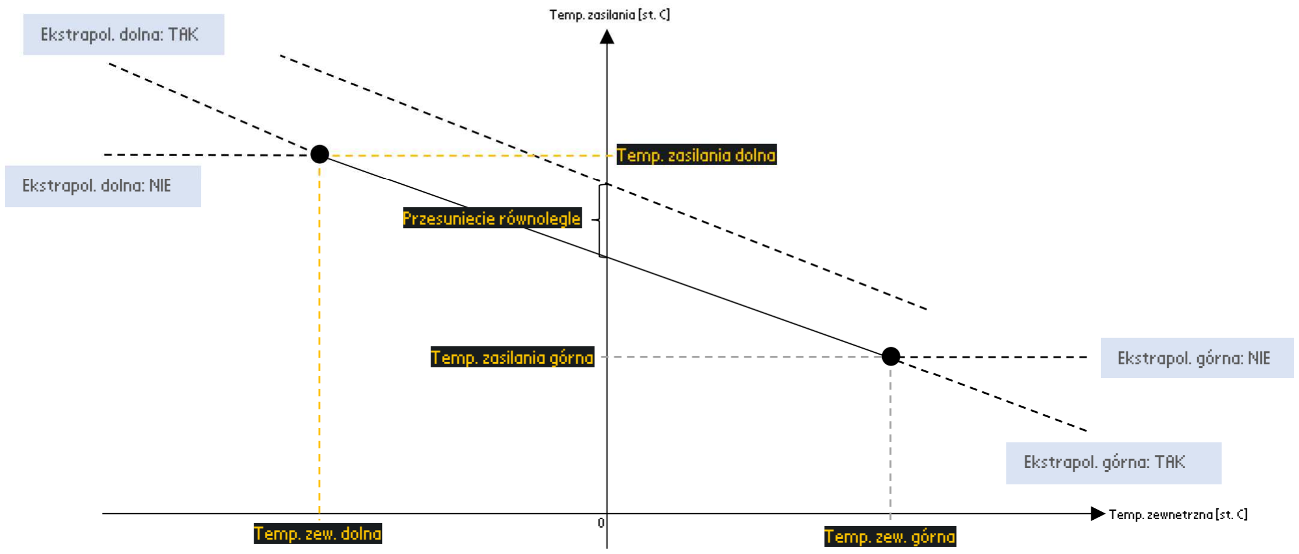
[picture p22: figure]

©2024
v1.0.0.
FabLabPro | 1 7 / 1 9

### 8. Obsługa

Obsługa sterownika jest intuicyjna, dodatkowego komentarza wymaga jedynie kilka funkcji:

8.1 „Sposób sterowania” w menu „Ogólne”:

Do wyboru są dwa tryby pracy:

- „Emulacja jednostki wewnętrznej” – w tym trybie AHU32bit zachowuje się tak jak fabryczny sterownik z jednostki wewnętrznej.
- „Tryb PRO” – w tym trybie AHU32bit włącza swój wewnętrzny regulator PI i steruje proporcjonalnie pracą agregatu.
8.2 „Krzywa grzewcza” w menu „Ustawienia CO”

Krzywą grzewczą definiujemy podając współrzędne dwóch punktów. Pozostałe wartości zostaną obliczone przez algorytm krzywej.

Opis parametryczny krzywej grzewczej:

ver. 1.0.0.

©2024
v1.0.0.
FabLabPro | 1 8 / 1 9

8.3 „Łagodny defrost” w menu „Defrsot”

Funkcja łagodny defrost ogranicza częstotliwość pracy sprężarki podczas defrostu do zadanej wartości. Fabrycznie defrost osiąga częstotliwość 85Hz+.

W przypadku przekroczenia częstotliwości defrost zostanie przerwane, ponowny defrost wywoływany jest po przerwie około 3 min. Defrost jest powtarzany, do momentu osiągnięcia temperatury 20°C na parowniku.

8.4 „Wymuś defrost” w menu „Defrost”

Funkcja wymuś defrost wymusza przeprowadzenie defrostu, niezależnie od stanu systemu.

Uwaga! Po wywołaniu funkcji, funkcja defrostu pozostanie aktywna do momentu jej wyłączenia w menu lub do momentu wyłączenia sterownika AHU32bit.

### 8.5 Strojenie regulatorów CO i CWU

Ważne!

Strojenie należy przeprowadzać bez pospiechu. Cechą dużych obiektów ciepłych jest spora bezwładność. Strojąc układ należy zmieniać w jednym kroku tylko jedna nastawię. Kolejna korektę należy wprowadzić dopiero po ustabilizowaniu się systemu.

Zwiększając stałą proporcjonalną kp oraz stałą całkującą ki regulator staje się szybszy i bardziej responsywny na zmiany temperatury. Nadmierne zwiększenie stałych może doprowadzić do rozchwiania systemu i pojawienia się oscylacji. Poprawnie nastrojony układ powinien utrzymywać zadaną temperaturę w zakresie +/-1.5°C

ver. 1.0.0.

©2024
v1.0.0.
FabLabPro | 1 9 / 1 9

### 9. Gwarancja

Dostarczone części są objęte gwarancją. Producent nie bierze natomiast odpowiedzialności za montaż oraz instalację układu oraz pracę całego systemu. Okres gwarancji wynosi 1 rok od daty sprzedaży.

### 10. Słowniczek

ODU – Outdoor Unit – jednostka zewnętrzna, agregat. LCD – Liquid crystal display, wyświetlacz
LED – light emmiting diode, dioda świecąca
Firmware – oprogramowanie układowe
T_supply – temperature zasilana
T_return – tempreatura powrotu
T_gas – tempreatura rury gazowej
T_liquid – temperature rury cieczowej
Flow – przepływ
En. cons. (Energy consumed) – energia konsumowana

### 11. Producent

FabLabPro
Wyprodukowano w Polsce
Wszystkie prawa zastrzeżone.

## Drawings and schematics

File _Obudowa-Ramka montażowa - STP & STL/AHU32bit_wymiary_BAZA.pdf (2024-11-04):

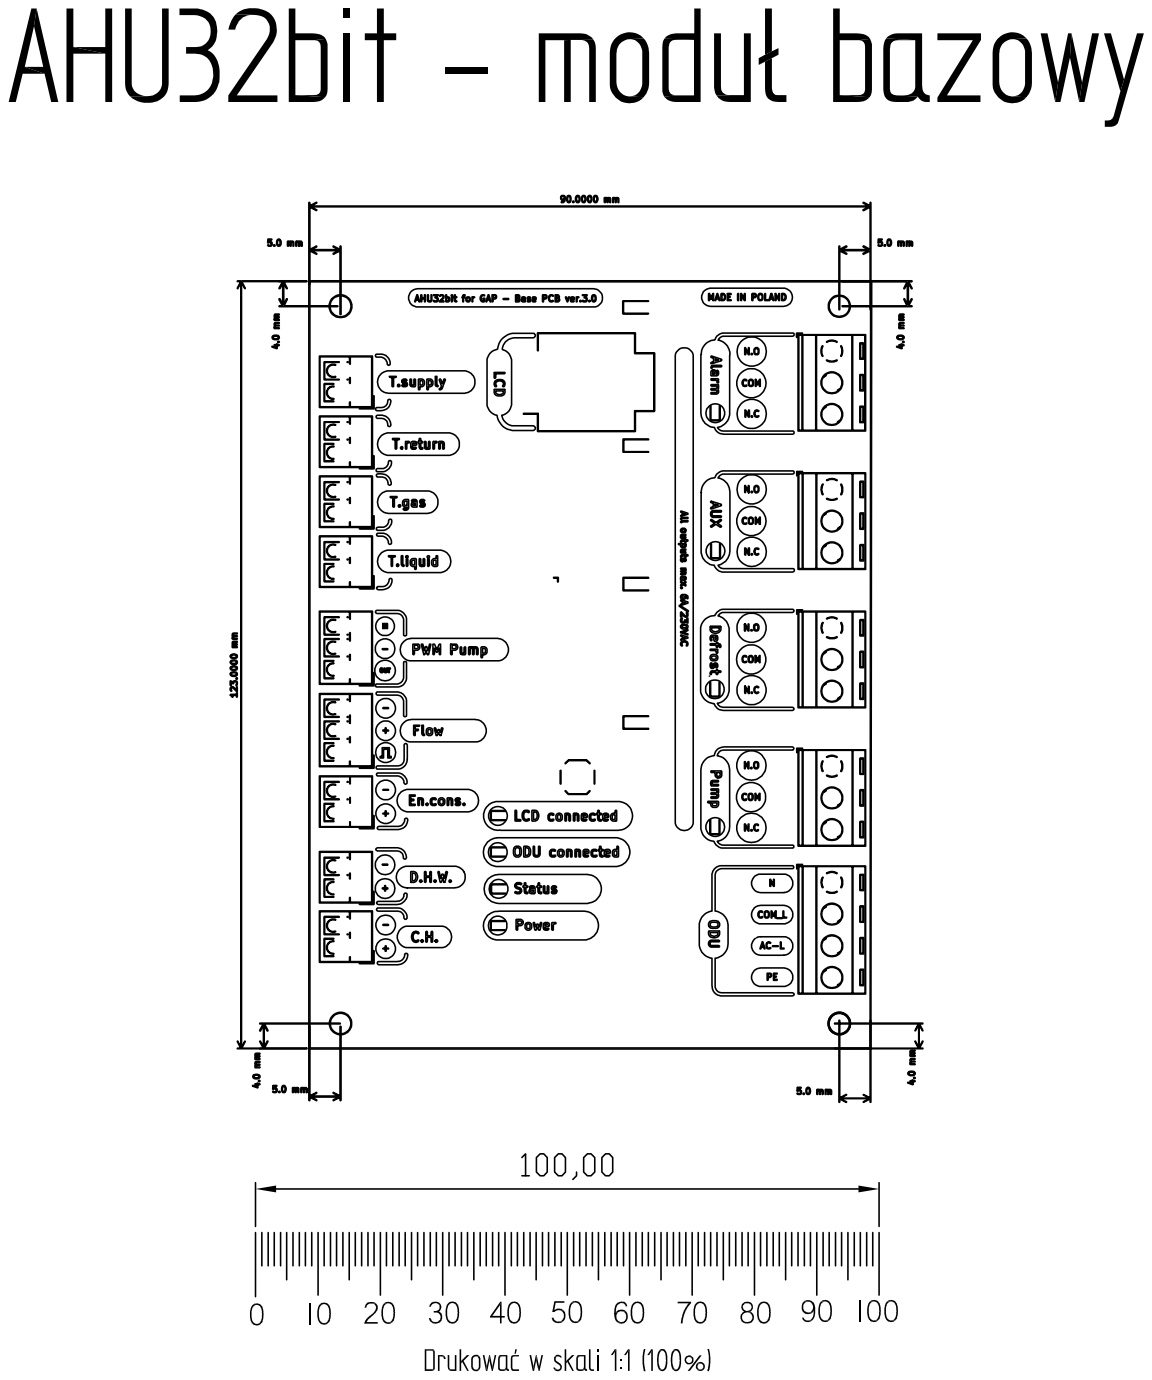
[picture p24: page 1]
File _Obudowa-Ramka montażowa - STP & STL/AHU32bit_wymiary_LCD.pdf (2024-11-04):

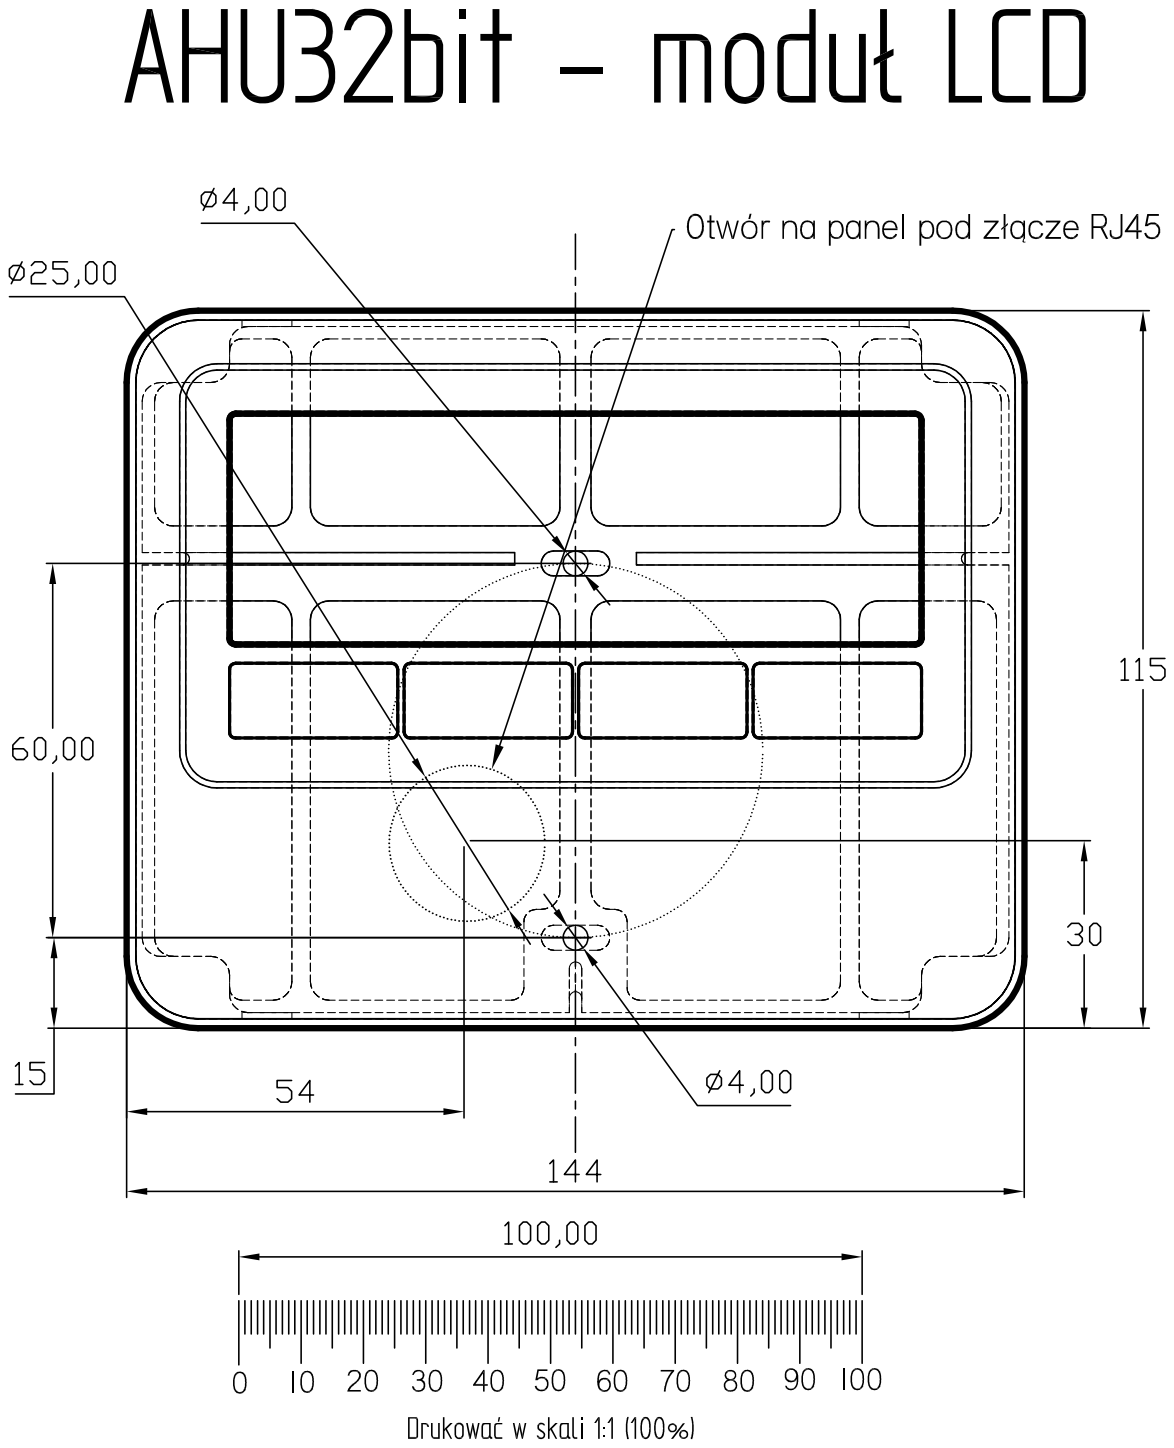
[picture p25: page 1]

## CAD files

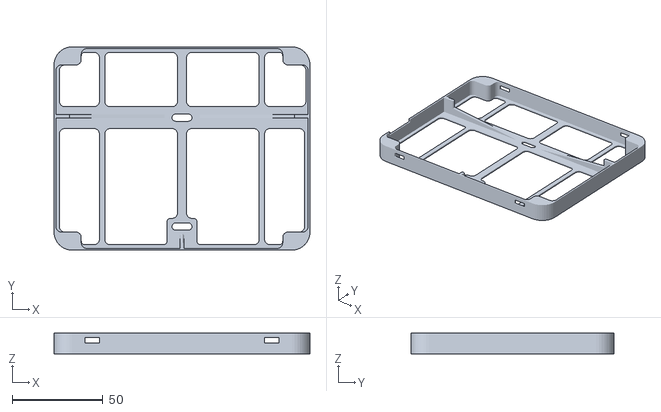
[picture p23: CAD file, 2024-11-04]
_Obudowa-Ramka montażowa - STP & STL/AHU32bit - ramka - plaska.STL
141.0 x 112.0 x 11.5

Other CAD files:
_Obudowa-Ramka montażowa - STP & STL/AHU32bit - ramka.STEP
_Obudowa-Ramka montażowa - STP & STL/AHU32bit - ramka.sldprt
